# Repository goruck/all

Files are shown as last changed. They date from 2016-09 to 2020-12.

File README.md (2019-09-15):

*NEW - ALL now supports Raspberry Pi 3 running Raspbian Buster + PREEMPT-RT patched kernel 4.19.59-rt23-v7+.*

# What is Alexa Lambda Linux (ALL) Project?
* ALL is an end-to-end HW/SW reference design created to enable quick prototyping and realization of the control and monitoring of things using Amazon’s Alexa.
* ALL includes Amazon’s Alexa Skills Kit and Lambda running in the cloud as well as a local server based on real-time Linux running on the Raspberry Pi.
* ALL also includes machine learning capabilities at the edge. 
* A voice-controlled home security system was built from ALL as an early proof of concept.
* ALL was introduced in late 2015 at https://github.com/goruck/all.

# ALL System Block Diagram

mall blockdia

# ALL Overview
Using voice to interface with devices and services around the home enables a rich and intuitive experience as shown by Amazon's huge successes with FireTV and Echo. However, with the exception of a few 3rd party point solutions such as WeMo, the voice user interface is generally not available in the home. One reason for this is the difficulty and unfamiliarity of the technologies required to enable voice control.

Alexa Lambda Linux (ALL) was developed to help accelerate this learning curve. ALL is a HW/SW reference design meant to enable quick prototyping and realization of the control and monitoring of things using Amazon's Alexa. A voice-controlled home security system was first built from the reference design as proof of concept which was later extended to support machine learning. 

The README below describes the system, the main components, its design, and implementation. It is expected that people will find it useful in creating voice user interfaces of their own using Alexa, Lambda, Linux, and the Raspberry Pi.

Feature | Benefit
------------ | -------------
Integrated with Lambda and ASK | Quick bring-up of new voice controls
Real-time Linux / user space app dev model | Low effort to control fast real-world events
Raspberry PI, open source, AWS services | Low cost and quick deployment
End to end SSL/TLS integration | Customer data security

# Table of Contents
1. [Requirements and System Architecture](https://github.com/goruck/all#requirements-and-system-architecture)
2. [Design and Implementation of the Main Components](https://github.com/goruck/all#design-and-implementation-of-the-components)
   1. [Alexa Intent Schema / Utterance database](https://github.com/goruck/all#alexa-intent-schema--utterance-database)
   2. [AWS Lambda function](https://github.com/goruck/all#aws-lambda-function)
   3. [Raspberry Pi Controller / Server](https://github.com/goruck/all#raspberry-pi-controller--server)
   4. [Keybus to GPIO Interface Unit](https://github.com/goruck/all#keybus-to-gpio-interface-unit)
3. [Machine Learning with ALL](https://github.com/goruck/all/blob/master/README.md#machine-learning-with-all)
   1. [Background Information](https://github.com/goruck/all/blob/master/README.md#background-information)
   2. [Problem Definition](https://github.com/goruck/all/blob/master/README.md#problem-definition)
   3. [Data Preparation](https://github.com/goruck/all/blob/master/README.md#data-preparation)
   4. [Data Analysis](https://github.com/goruck/all/blob/master/README.md#data-analysis)
   5. [Algorithm Evaluation](https://github.com/goruck/all/blob/master/README.md#algorithm-evaluation)
   6. [Implementation](https://github.com/goruck/all/blob/master/README.md#implementation)
   7. [Results](https://github.com/goruck/all/blob/master/README.md#results)
4. [Development and Test environment](https://github.com/goruck/all#development-and-test-environment)
5. [Overall Hardware Design and Considerations](https://github.com/goruck/all#overall-hardware-design-and-considerations)
6. [Bill of Materials and Service Cost Considerations](https://github.com/goruck/all#bill-of-materials-and-service-cost-considerations)
7. [Licensing](https://github.com/goruck/all/blob/master/README.md#licensing)
8. [Contact Information](https://github.com/goruck/all/blob/master/README.md#contact-information)
9. [Appendix](https://github.com/goruck/all#appendix)

# Requirements and System Architecture
Please see below the high-level requirements that the project had to meet.

* Low cost
* Extensible / reusable with low effort
* Secure
* Enable fast prototyping and development
* Include at least one real world application

Meeting these requirements would prove this project useful to a very wide variety of voice interface applications. In addition, implementing a non-trivial "real-world" application would show that the design is robust and capable. Hence the last requirement, which drove the implementation of a voice user interface on a standard home security system, the DSC Power832.

The system needs both cloud and (home-side) device components. Amazon's Alexa was selected as the cloud speech service and Amazon Web Services' Lambda was selected to handle the cloud side processing required to interface between Alexa and the home-side devices. Alexa is a good choice given that its already integrated with Lambda and has a variety of voice endpoints including Echo and FireTV and it costs nothing to develop voice applications via the [Alexa Skills Kit](https://developer.amazon.com/public/solutions/alexa/alexa-skills-kit). [Lambda](https://aws.amazon.com/lambda/) is ideal for quickly handling bursty processing loads, which is exactly what is needed to control things with voice. It also has a free tier under a certain amount of processing and above that its still very inexpensive. So, Alexa and Lambda are reasonable cloud choices given the requirements above.

The [Raspberry Pi 2](https://www.raspberrypi.org/blog/raspberry-pi-2-on-sale/) was designated as the platform to develop the home-side device components( All also supports the Raspberry Pi 3.) The platform has a powerful CPU, plenty RAM, a wide variety of physical interfaces, has support for many OSs, and is inexpensive. It is possible to use an even more inexpensive platform like [Arduino](https://www.arduino.cc/) but given its lower capabilities vis-a-vis the Raspberry PI this would limit the types of home-side applications that could be developed. For example, use of GNU/Linux is desirable in this project for extensibility and rapid development reasons. Arduino isn't really capable of running Linux but the Pi is. The downside of using the Pi plus a high-level OS like vanilla Linux is that the system cannot process quickly changing events (i.e., in "real-time"). On the other hand, the Arduino running bare metal code is a very capable real-time machine. To be as extensible as possible, the system needs to support the development of real-time voice controlled applications and without complex device side architectures like using an Arduino to handle the fast events connected to a Pi to handle the complex events. Such an architecture would be inconsistent with the project requirements. Therefore [real-time Linux](https://wiki.linuxfoundation.org/realtime/start) was chosen as the OS on the Pi. However, this comes with the downsides of using a non-standard kernel and real-time programming is less straightforward than standard application development in Linux userspace.

In the reference design, the Pi's GPIOs are the primary physical interface to the devices around the home that are enabled with a voice UI. This allows maximum interface flexibility, and with using real-time Linux, the GPIO interface runs fast. The reference design enables GPIO reads and writes with less than 60 us latency, vanilla Linux at best can do about 20 ms. Of course, all the other physical interfaces (SPI, I2C, etc.) on the Pi are accessible in the reference design though the normal Linux methods.

The requirements and the analysis above drove a system architecture with the following components.

* Alexa Skills developed using the Alexa Skills Kit
* An AWS Lambda function in Node.js to handle the intent triggers from Alexa and send it back responses from the home device 
* A home device built on Raspberry PI running real-time Linux with a server application developed in C running in userspace
* A hardware interface unit that handled the translation of the electrical signals between the Pi and the security system
* The DSC Power832 security system connected via its Keybus interface to the Pi's GPIOs via the interface unit.

Note that although the development of the architecture described above appears very waterfall-ish, the reality is that it took many iterations of architecture / design / test to arrive at the final system solution.

# Design and Implementation of the Components

## Alexa Skills
Creating Alexa Skills (which are essentially voice apps) is done by using the Alexa Skills Kit. An Amazon applications developer account is required to get access to the [Alexa Skills Kit (ASK)](https://developer.amazon.com/public/solutions/alexa/alexa-skills-kit), one can be created one at https://developer.amazon.com/appsandservices. There's a [getting started guide](https://developer.amazon.com/appsandservices/solutions/alexa/alexa-skills-kit/getting-started-guide) on the ASK site on how to create a new skill. The skill developed to control the alarm panel, named *panel*, used the example skill *color* as a starting point. Amazon makes the creation of a skill relatively easy but careful thinking through the voice interaction is required. The *panel* skill uses a mental model of attaching a voice command to every button on the alarm's keypad and an extra command to give the status of the system. The alarm system status is the state of the lights on the keypad (e.g., armed, bypass, etc). Four-digit code input is also supported, which is useful for a PIN. The Amazon skill development tool takes you through the following steps in creating the skill:

1. Skill Information - Invocation Name, Version, and Service Endpoint (the Lambda ARN in this project)
2. Interaction Model - Intent Schema, Custom Slot Types, and Sample Utterances
3. Test
4. Description
5. Publishing Information (the *panel* skill is not currently published)

The creation of the *panel* skill required inputting of an [Intent Schema](https://github.com/goruck/all/blob/master/ask/IntentSchema.txt) (which defines the voice interaction model), [sample utterances](https://github.com/goruck/all/blob/master/ask/SampleUtterances.txt), and [custom slot definitions](https://github.com/goruck/all/blob/master/ask/CustomSlotTypes.txt) which are essentially elaborations of the values of parameters used in the Intent Schema. The ASK service will generate a voice model from these inputs. 

The table below shows some of the mapping between example user requests and the sample utterance syntax used in the interaction model. 

Example User Request | Sample Utterance
---------------------|------------------
“Alexa, ask Panel for its status” | WhatsMyStatusIntent its status
“Alexa, ask Panel about its status” |WhatsMyStatusIntent its status
“Alexa, ask Panel for the status” | WhatsMyStatusIntent the status
“Alexa, ask Panel about the status” | WhatsMyStatusIntent the status
“Alexa, ask Panel for status” | WhatsMyStatusIntent status
“Alexa, ask Panel about status” | WhatsMyStatusIntent status
“Alexa, ask Panel for the status” | WhatsMyStatusIntent the status
“Alexa, ask Panel about the status” | WhatsMyStatusIntent the status
“Alexa, ask Panel what is the status” | WhatsMyStatusIntent what is the status
“Alexa, ask Panel what the status is” | WhatsMyStatusIntent what the status is
“Alexa, ask Panel what's the status” | WhatsMyStatusIntent what's the status
“Alexa, ask Panel to give me the status” | WhatsMyStatusIntent give me the status
“Alexa, ask Panel to give me its status” | WhatsMyStatusIntent give me its status
“Alexa, ask Panel to tell me the status” | WhatsMyStatusIntent tell me the status
“Alexa, ask Panel to tell me its status” | WhatsMyStatusIntent tell me its status
"Alexa, ask Panel for key pound" | MyNumIsIntent key {Keys}
"Alexa, ask Panel for button star" | MyNumIsIntent button {Keys}
"Alexa, ask Panel for key pad button 0" | MyNumIsIntent key pad button {Keys}
"Alexa, ask Panel for 8" | MyNumIsIntent {Keys}
"Alexa, ask Panel for pin 1234" | MyCodeIsIntent pin {Code}
"Alexa, ask Panel for code 5678" | MyCodeIsIntent code {Code}
"Alexa, ask Panel for 4545" | MyCodeIsIntent {Code}

The "LIST_OF_KEYS" slot enables the intent "MyNumIsIntent" to activate when Alexa hears the name of the buttons on the keypad defined by the slot. The intent "WhatsMyStatusIntent" activates when Alexa hears any of the status related utterances listed above. The intent "MyCodeIsIntent" activates when Alexa hears a 4-digit code. When the intents activate, they cause the service endpoint Lambda function to run and perform specific processing depending on the user intent.

The skill is invoked by saying to Alexa "ask panel" or "tell panel".

## AWS Lambda function
An Amazon Web Services account is needed to use Lambda, one can be created at at https://aws.amazon.com/. Like all AWS products, there is good [documentation](https://aws.amazon.com/lambda/) available on the AWS site that should be read to come up to speed, if not already familiar. Still it can be challenging to use the product, if unfamiliar with javascript, Node, and asynchronous programming which are all essential to using Lambda. Several books and articles including [*Sams Teach Yourself Node.js in 24 Hours*](http://smile.amazon.com/dp/0672335956) by Ornbo, [*JavaScript: The Good Parts*](http://smile.amazon.com/dp/0596517742) by Crockford, and [*Asynchronous programming and continuation-passing style in JavaScript*](http://www.2ality.com/2012/06/continuation-passing-style.html) by Rauschmayer can help to accelerate the learning curve. Lambda and Node.js is very well-suited to scale cloud side processing associated with applications like voice control, given that Lambda was designed to handle bursty applications and the non-blocking I/O benefits of Node.js.

The *color* skill and Lambda function example provided by ASK was used as a template to create the Lambda function for *panel*. Since the Lambda function needed to talk to a remote Raspberry Pi server, that functionality was added as well as modifying the logic and speech responses to suit the alarm application. The Lambda code uses the Node.js tls method to open, read, and write a TCP socket that connects to the remote Pi server which sends commands to and reads status from the panel. The tls method provides both authentication and encryption between the Lambda client and the Pi server. One of the biggest challenges in this development is the placement of the  callbacks that returned responses back to Alexa due to the async nature of Node.js. The rest of the Lambda function development was straightforward. 

The Lambda code is divided up into three parts, [all.js](https://github.com/goruck/all/blob/master/lambda/all.js) contains most of the functions required to process the speech intents from the Alexa service and interface to the local Pi in a client - server model. However, some Lambda code requires it to be released under the Amazon License which is in the [amzn](https://github.com/goruck/all/tree/master/lambda/amzn) directory. Lastly, the Lambda code common to all.js and the code in the amzn directory is in [shared.js](https://github.com/goruck/all/blob/master/lambda/shared.js).

## Raspberry Pi Controller / Server

### Real-time Linux
The Linux disto on the Pi is based on Debian 10 "Buster" with a custom built [Raspberry Pi Linux 4.19.y kernel](https://github.com/raspberrypi/linux/tree/rpi-4.19.y-rt) patched with rt-patch and configured as a fully preemptible kernel. The kernel was cross-compiled on a Linux host using the official [Raspberry Pi instructions](https://www.raspberrypi.org/documentation/linux/kernel/building.md) and [LeMaRiva's excellent HOWTO](https://lemariva.com/blog/2019/09/raspberry-pi-4b-preempt-rt-kernel-419y-performance-test) as guides. Also the wiki [real-time Linux](https://wiki.linuxfoundation.org/realtime/start) is an invaluable source of information on the rt-patch and how to write real-time code.

The latency of the patched kernel was measured using [Cyclictest](https://wiki.linuxfoundation.org/realtime/documentation/howto/tools/cyclictest/start) which showed a worse case latency of less than 135 us. So, that seemed to indicate that applications could reliably respond to events up to about 7.4 kHz which is sufficient for this application which needs to respond to events at a 1 KHz rate (see below).

The distribution of the latency on the patched kernel as measure by Cyclictest is shown below.

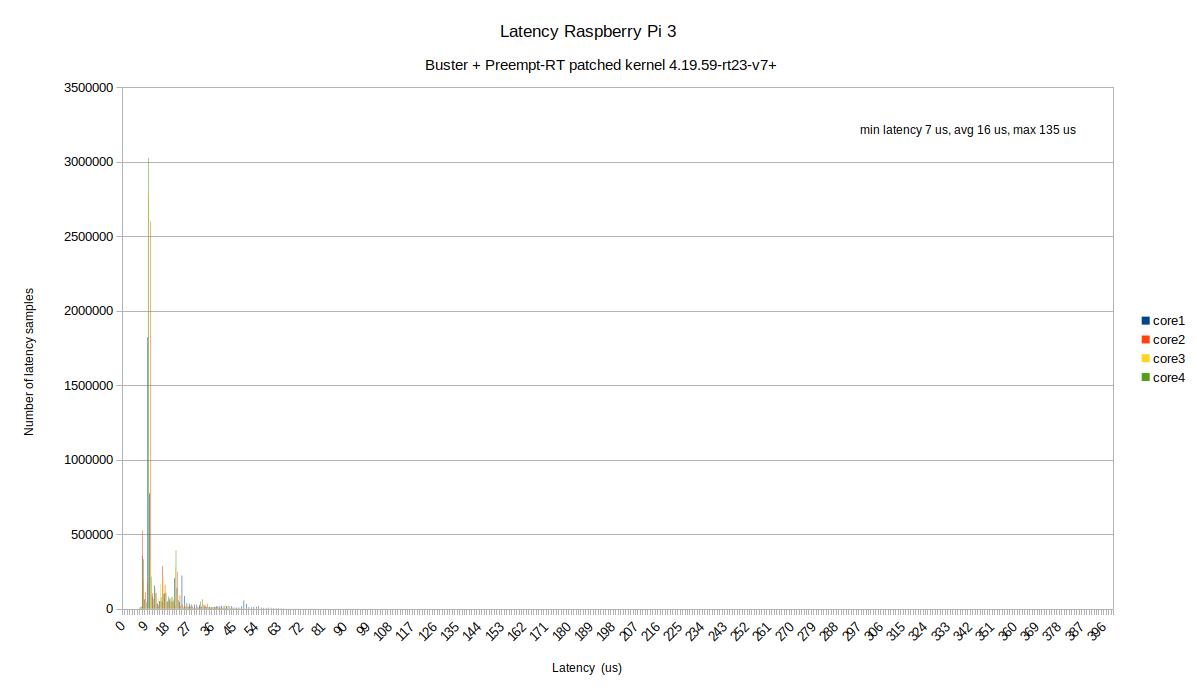
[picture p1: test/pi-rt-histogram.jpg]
pi latency


### Controller / Server Application
The application code on the Pi emulates a DSC keypad controller running in the Linux system's userspace. The application code in its entirety can be found [here](https://github.com/goruck/all/blob/master/rpi/kprw-server.c), this section captures important design considerations that are not obvious from the code itself or the comments therein.

The DSC system is closed and proprietary and besides the installation and programming information in the DSC manuals and what hackers have managed to figured out and posted on the Internet and GitHub, there isn't much information available about the protocol it uses to communicate with its keypads. Also, much of of what is on the Internet relies on using an IP interface bridge like this [one](http://www.eyezon.com/?page_id=176) from Eyezon. A bridge like this instead of the code on the Raspberry Pi could have been used in this project but that would have made the reference design much less generic (and much less fun to develop). A lot of useful information on how to hack the DSC system can be found in the [Arduino-Keybus](https://github.com/emcniece/Arduino-Keybus) GitHub repo, but this project uses an Arduino which was ruled out (see above) and it was read-only. Still, it is very educational. Although these sources helped, a lot of reverse engineering was required to figure out the protocol used on the DSC Keybus. The reverse engineering mainly consisted of using an early version of the application code to examine the bits sent from the panel to the keypads and the keypads to the panel in response to keypad button presses and other events, like motion and door / window openings and closings. It was determined that the first two bytes of each message indicates its type, followed by a variable number of data bits including error protection. For example a message with its first two bytes equal to 0x05 is telling the keypad to illuminate specific status LEDs, such as BYPASS, READY, etc and a message type equal to 0xFF indicates keypad to panel data is being sent. See the *decode()* function in the application code for details regarding the various message types and their contents.

The application code consists of three main parts:

* A thread called *panel_io()* that handles the bit-level processing needed to assemble messages from the keybus serial data
* A thread called *msg_io()* that handles the message-level output processing
* A server called *panserv()* running in the main thread that communicates with an external client for commands and status

The application code directly accesses the GPIO's registers for the fastest possible reads and writes. The direct access code is based on [this](http://elinux.org/RPi_GPIO_Code_Samples#Direct_register_access) information from the Embedded Linux Wiki at elinux.org. The function *setup_io()* in the application code sets up a memory regions to access the GPIOs. The information in the Broadcom BCM2835/6 ARM Peripherals document is very useful to understand how to safely access the Pi's processor peripherals. It is [here](http://elinux.org/RPi_Documentation) on the Embedded Linux Wiki site.

Inter-thread communication is handled safely via read and write FIFOs without any synchronization (e.g., using a mutext). Its not desirable to use conventional thread synchronization methods since they would block the *panel_io()* thread. There is no way (to my knowledge) to tell the panel not to send data on the keybus, so if *panel_io()* was blocked by another thread accessing a shared FIFO, the application code would drop messages. A good solution to this problem was found in the article [Creating a Thread Safe Producer Consumer Queue in C++ Without Using Locks](http://blogs.msmvps.com/vandooren/2007/01/05/creating-a-thread-safe-producer-consumer-queue-in-c-without-using-locks/) by Vandooren, which is what was implemented with a few modifications.

Running code under real-time Linux requires a few special considerations. Again, the [real-time Linux](https://rt.wiki.kernel.org/index.php/Main_Page) wiki was used extensively to guide the efforts in this regard. The excellent book [The Linux Programming Interface](http://man7.org/tlpi/) by Kerrisk also was very helpful to understand more deeply how the Linux kernel schedules tasks. There are three things needed to be set by a task in order to provide deterministic real time behavior:

1. Setting a real time scheduling policy and priority by use of the *sched_setscheduler()* system call and its pthread cousins. Note that *panel_io()*, *message_io()*, and *main()* were all given the same scheduling policy (SCHED_FIFO) but *panel_io()* has a higher priority than *message_io()* and *main()*. This was done to ensure that the bit-level processing would have enough time to complete. 
2. Locking memory so that page faults caused by virtual memory will not undermine deterministic behavior. This is done with the *mlockall()* system call. 
3. Pre-faulting the stack, so that a future stack fault will not undermine deterministic behavior. This is done by simply accessing each element of the program's stack by use of the *memset()* system call. 

Extensive use of the *clock_nanosleep()* function from librt is used in the code. For example, its use is shown in the *panel_io()* thread where it awakens the thread every INTERVAL (10 us) to read and write to the GPIOs driving the keybus clock and data lines (via the interface unit). The thread contains logic to detect the start of word marker, to detect high and low clock periods, and to control precisely when the GPIOs are read and written. The below taken from *panel_io()* causes the thread to wait for valid data before reading the GPIO.

```c
t.tv_nsec += KSAMPLE_OFFSET;
tnorm(&t);
clock_nanosleep(CLOCK_MONOTONIC, TIMER_ABSTIME, &t, NULL); // wait KSAMPLE_OFFSET for valid data
wordkr_temp = (GET_GPIO(PI_DATA_IN) == PI_DATA_HI) ? '0' : '1'; // invert
```

Even though the *panel_io()* is given higher priority than the other two threads, other critical threads in the Linux kernel must have higher still priority for the overall system to function. Therefore it is possible that a higher priority kernel task could preempt *panel_io()* and cause it to drop bits. The real-time Linux wiki suggests this solution:

*"In general, I/O is dangerous to keep in an RT code path. This is due to the nature of most filesystems and the fact that I/O devices will have to abide to the laws of physics (mechanical movement, voltage adjustments, <whatever an I/O device does to retrieve the magic bits from cold storage>). For this reason, if you have to access I/O in an RT-application, make sure to wrap it securely in a dedicated thread running on a disjoint CPU from the RT-application."* 

Based on this, the *panel_io()* thread was locked to its own CPU and the other threads are locked to the other three CPUs (its really great to have four CPUs at one's disposal). The application code sets the thread CPU affinity as shown below. 

```c
// CPU(s) for main, predict and message i/o threads
  CPU_ZERO(&cpuset_mio);
  CPU_SET(1, &cpuset_mio);
  CPU_SET(2, &cpuset_mio);
  CPU_SET(3, &cpuset_mio);
  CPU_ZERO(&cpuset_main);
  CPU_SET(1, &cpuset_main);
  CPU_SET(2, &cpuset_main);
  CPU_SET(3, &cpuset_main);
  // CPU(s) for panel i/o thread
  CPU_ZERO(&cpuset_pio);
  CPU_SET(0, &cpuset_pio);
```

With the threads pinning to the CPUs in this way and with the priority of *panel_io()* being greater than the other two threads in the application code (but not greater than the kernel's critical threads), the system exhibits robust real-time performance.

The server uses openSSL for authentication and encryption. For development and test purposes self-signed certificates are used. The cert and key pairs are generated with the following commands.

```bash
# Step 1. Generate ca private key
$ openssl genrsa -out /home/pi/certs/ca/ca.key 4096
# Step 2. Create self-signed ca cert, COMMON_NAME="My CA"
$ openssl req -new -x509 -days 365 -key /home/pi/certs/ca/ca.key -out /home/pi/certs/ca/ca.crt -sha256
# 
# Step 3. Create client private key
$ openssl genrsa -out /home/pi/certs/client/client.key 2048
# Step 4. Create client cert signing request, COMMON_NAME="Client 1"
$ openssl req -new -key /home/pi/certs/client/client.key -out /home/pi/certs/client/client.csr -sha256
# Step 5. Create signed client cert
$ openssl x509 -req -days 365 -in /home/pi/certs/client/client.csr -CA /home/pi/certs/ca/ca.crt -CAkey /home/pi/certs/ca/ca.key -set_serial 01 \
-out /home/pi/certs/client/client.crt -sha256
# 
# Step 6. Create server private key
$ openssl genrsa -out /home/pi/certs/server/server.key 2048
# Step 7. Create server cert signing request, COMMON_NAME="localhost"
$ openssl req -new -key /home/pi/certs/server/server.key -out /home/pi/certs/server/server.csr -sha256
# Step 8. Create signed server cert, where "key.ext" contains "subjectAltName = IP:xxx.xxx.xxx.xxx"
$ openssl x509 -req -days 365 -in /home/pi/certs/server/server.csr -CA /home/pi/certs/ca/ca.crt -CAkey /home/pi/certs/ca/ca.key -set_serial 02 \
-out /home/pi/certs/server/server.crt -sha256 -extfile /home/pi/certs/server/key.ext
# 
# Step 9. Copy client key pair and CA certificate to Lambda
$ cp /home/pi/certs/client/client.crt /home/pi/all/lambda
$ cp /home/pi/certs/client/client.key /home/pi/all/lambda
$ cp /home/pi/certs/ca/ca.crt /home/pi/all/lambda
```

Note: replace the X's in key.ext with the IP address or hostname of your server.

Production code should use certificates signed by a real CA. The server also uses TCP Wrapper daemon for secure access. TCP Wrapper uses the *hosts_ctl()* system call from libwrap library to limit client access via the rules defined in /etc/host.deny and /etc/host.allow files. The rules are set so that only clients with local IP addresses and AWS IP addresses are allowed access to the server.

The application code needs to be compiled with the relevant libraries and executed with su privileges, per the following.

```bash
# Install libs if needed.
$ sudo apt install libwrap0-dev libssl-dev
# Compile kprw-server.c.
# To enable R logging, add -DRLOG=\"/home/pi/all/R/rlog.txt\" (change path as required).
# To output status messages to stdout, add -DVERBOSE.
# To run a real-time safe test at start of program, add -DTESTRT.
$ gcc -Wall -o kprw-server kprw-server.c -lrt -lpthread -lwrap -lssl -lcrypto
# Start program.
# PORTNUM=69840 # TCP port number for the server to use (change as required).
$ sudo ./kprw-server $PORTNUM
```

### Startup
The Raspberry Pi is used here as an embedded system so it needs to come up automatically after power on, including after a possible loss of power. The application code defines the GPIOs as follows:

```c
// GPIO pin mapping.
#define PI_CLOCK_IN	(13) // BRCM GPIO13 / PI J8 Pin 33
#define PI_DATA_IN	(5)  // BRCM GPIO05 / PI J8 Pin 29
#define PI_DATA_OUT	(16) // BRCM GPIO16 / PI J8 Pin 36
``` 

These GPIOs need to be in a safe state after power on and boot up. Per the Broadcom BCM2835/6 ARM Peripherals document, these GPIOs are configured as inputs at reset and the kernel doesn't change that during boot, so they won't cause any the keybus serial data line to be pulled down before the application code initializes them. The BRCM GPIO16 was selected for the active high signal that drives the keybus data line since that GPIO has the option of being driven low from an external pull down. Other GPIOs have optional pull-ups. Even though the pull resistors are disabled by default, this removes the possibility of the keybus data line becoming active if software somehow enabled the pull resistor by mistake.

A known problem of the Raspbian Preempt-RT patches is that the IRQ/39-dwc_otg process can use a lot the CPU (~30%) which is caused by servicing the USB irq. Although this should not affect the real-time performance of this application given the thread priority settings, the USB ports can be disabled if they are not being. Since the RPi3's wifi chip is connected via SDIO to the processor and nothing else was needed to be connected to the USB ports they are disabled on startup in this configuration to improve the responsiveness of the system. This is done by [power-off-usb.sh](./scripts/power-off-usb.sh) script which is run by /etc/rc.local at startup. 

The kprw-server application is run as a Linux service enabled to run at boot time. See [kprw-server.service](./rpi/kprw-server.service).

## Keybus to GPIO Interface Unit

### Keybus Electrical and Timing Characteristics
The keybus is a DSC proprietary serial bus that runs from the panel to the sensors and controller keypads in the house. This bus needs to understood from an electrical, timing, and protocol point of view (see above) before the Pi can be interfaced to the panel. There isn't a lot of information on the keybus other than what's in the DSC installation manual and miscellaneous info on the Internet posted by hackers. Essentially, this is a two wire bus with clock and data, plus ground and the supply from the panel. The supply is 12 V (nominal) and the clock and data transition between zero volts and the supply voltage level (i.e., 0 to 12 V nominally but could be a bit more or less (~ +/-10%) depending on the specific panel). The large voltage swings make sense given that it provides good noise immunity against interference picked up from long runs of the bus through the house. The DSC manual states that the bus supply can source a max of 550 mA. The sum of the current from all the devices presently on the bus was about 400 mA. This meant that the interface unit could draw no more than 150 mA.

An oscilloscope was used to reverse engineer the protocol. Some screen-shots and analysis from them are below.

whole-word-ann

This shows an entire word with the start of new word marker, which is the clock being held high for a relatively long time. The clock rate when active is 1 KHz. The messages between the panel and keypads are of variable length. The typical message from the panel to the keypads is 43 bits (43 ms in duration) and the start of the new word clock marker is about 15 ms. Thus, a typical message time including start of new marker is about 58 ms. Messages can be up to 62 bits long but they are not frequent. 

data-clock-close

This shows a closer view of the clock and data, with data being sent between the panel and keypad and vice-versa. Data from the panel to the keypads transitions on the rising edge of the clock and becomes valid about 120 us later. Data from the keypads to the panel transitions at falling edge of the clock is likely registered in the panel on the next rising edge of the clock. The keypad data needs to be held for at least 25 us after the rising edge of the clock for it to be properly registered. Timers in the Pi's application code must adhere to these values for reliable data transfers to happen. The spikes at 2.5 and 4.5 ms are most likely due to the pull-up resistor on the data line in the panel causing it to be pulled high before the driver on the keypad has a chance to pull it low, which happens when the keypad sends a 0 bit to the panel.

From this data, it is clear that the panel's data line is bidirectional (with direction switched by clock level) and pulled up internally when configured as an input. The strength of the pull-up resister needs to be known in order to design the interface circuit correctly and via experimentation it was determined to be approximately 5 KΩ.

Note that a means to prevent or mitigate keybus data corruption needs to be implemented since ALL may try to write to the panel at the same time as a keypad. This is done in the rpi code by checking for very short words sent by the panel on the keybus. The panel outputs short words (usually 9-bits) which are ignored as invalid since these short words are usually associated with the simultaneous transfer of keypad data to the panel (recall from above the keybus is bidirectional and bits are transferred on the rising and falling edge of the clock). This keypad data is sent in response to a panel keypad query command that was sent previously. These commands include those messages starting with 0x051, 0x0593, 0x11 and possibly others.

### Raspberry Pi GPIO Electrical Characteristics
Data on the electrical characteristics of the Pi's GPIOs is also required to design the interface. There is not really the right level of detail available from the Raspberry Pi standard information. But there is excellent information on the Mosaic Industries' website [here](http://www.mosaic-industries.com/embedded-systems/microcontroller-projects/raspberry-pi/gpio-pin-electrical-specifications). This information is super helpful and detailed. Some of the key points from the article are below. 

* These are 3.3 volt logic pins. A voltage near 3.3 V is interpreted as a logic one while a voltage near zero volts is a logic zero. A GPIO pin should never be connected to a voltage source greater than 3.3V or less than 0V, as prompt damage to the chip may occur as the input pin substrate diodes  conduct. There may be times when you may need to connect them to out ­of ­range voltages – in those cases the input pin current must be limited by an external resistor to a value that prevents harm to the chip. I recommend that you never source or sink more than 0.5 mA into an input pin
* To prevent excessive power dissipation in the chip, you should not source/sink more current from the pin than its programmed limit. So, if you have set the current capability to 2 mA, do not draw more than 2 mA from the pin
* Never demand that any output pin source or sink more than 16 mA
* Current sourced by the outputs is drawn from the 3.3 V supply, which can supply only 50 mA maximum. Consequently, the maximum you can source from all the GPIO outputs simultaneously is less than 50 mA. You may be able to draw transient currents beyond that limit as they are drawn from the bypass capacitors on the 3.3 V rail, but don't push the envelope! There isn't a similar limitation on sink current. You can sink up to 16 mA each into any number of GPIO pins simultaneously. However, transient sink currents do make demands on the board's bypass capacitors, so you may get into trouble if all outputs switch their maximum current synchronously
* Do not drive capacitive loads. Do not place a capacitive load directly across the pin. Limit current into any capacitive load to a maximum transient current of 16 mA. For example, if you use a low pass filter on an output pin, you must provide a series resistance of at least 3.3V/16mA = 200 Ω

### Interface Circuit Design
Its desirable to electrically isolate the panel and Pi to prevent ground loops and optoisolators are an obvious choice. But they do consume a fair amount of current and the keybus data and clock lines cannot supply enough to directly drive them. Therefore, the keybus clock and data lines have buffers (CD4050) between them and the optoisolators. Out of an abundance of caution, buffers (74HC126) were also added between the clock and data optoisolators and the Pi's GPIOs, but they are not really needed since the Pi's GPIOs come out of reset being able to supply or sink 8 mA while the interface circuit only needs a 2 mA supply. The '126 buffers were removed in the final design. A high Current Transfer Ratio (CTR) optoisolator configured to drive a FET with logic-level gate voltage threshold was used to pull down the data line with sufficient strength. The other optoisolators are high CTR as well to minimize current draw from the panel. The interface schematic is shown below.

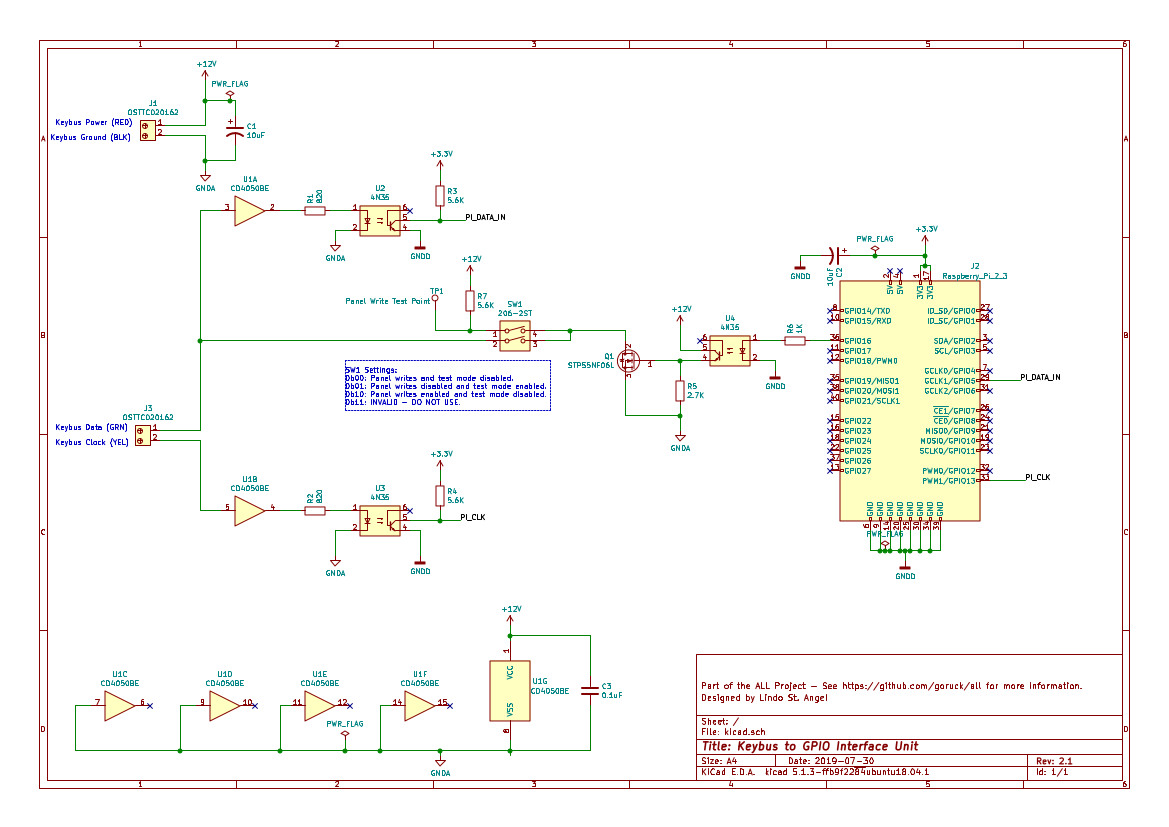
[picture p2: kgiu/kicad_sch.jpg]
interface


# Machine Learning with ALL
Adding machine learning (ML) capabilities to ALL was mainly motivated by a desire to use Alexa to help train a ML algorithm in an intuitive and low-friction manner by employing voice to ground truth (or 'tag') observations. Also since ALL uses a home security system as a proof-of-concept, ML seemed to be a natural fit given the amount of data captured by the security system's sensors. Door, window, and motion data is continually captured which reflects the movement of people into and around the house. Of course, normally this data is used for security monitoring purposes but here the goal of adding machine learning to ALL was to use this data to reliably predict patterns of people movement around the house that would trigger appropriate actions automatically. Using ML as described below can also be used to become familiar with the topic itself since the application is fairly straightforward and tractable.

Its important to note that simple rule based algorithms can be employed instead of ML to trigger actions based on the sensor data. However, this is really only feasible for the most basic patterns of movement around the house. 

## Background Information
### Training ML Models *(This section adapted from [here](http://docs.aws.amazon.com/machine-learning/latest/dg/training-ml-models.html))*
The process of training an ML model involves providing an ML algorithm (that is, the learning algorithm) with training data to learn from. The term ML model refers to the model artifact that is created by the training process.

The training data must contain the correct answer, which is known as a response. The learning algorithm finds patterns in the training data that map the input data predictors to the response (the answer that you want to predict), and it outputs an ML model that captures these patterns.

The ML model is used to get predictions on new data for which a response is not known.

### Steps to build and train a predictive ML model
1. Define the problem that predictive ML model will solve for.
2. Prepare the data that will be used to train the ML model.
3. Analyze the training data to help guide ML algo selection. 
4. Select a suitable algorithm for the ML model. 
5. Evaluate and optimize the ML model’s predictive accuracy.
6. Use the ML model to generate predictions.

### R
The popular open-source software R was selected as the main ML tool and was intended to be used for both modeling and embedded real-time purposes which helps to accelerate development by reusing code. The excellent book [An Introduction to Statistical Learning](http://smile.amazon.com/dp/B01IBM7790) was extensively used as both a learning guide to ML and to R.

The R software package was downloaded from [The R Project for Statistical Computing](https://www.r-project.org/) website and compiled on the Raspberry Pi since there are no recent pre-compiled packages available for Raspbian Wheezy. The following steps are required to install R on the Pi.

```bash
$ cd ~
$ wget http://cran.rstudio.com/src/base/R-3/R-3.6.1.tar.gz
$ mkdir R_HOME
$ mv R-3.6.1.tar.gz R_HOME/
$ cd R_HOME/
$ tar zxvf R-3.6.1.tar.gz
$ cd R-3.6.1/
$ sudo apt-get install gfortran libreadline-dev libx11-dev libxt-dev \
libbz2-dev liblzma-dev libpcre3-dev libcurl4-gnutls-dev
$ ./configure
$ make
$ sudo make install
```

Note that this installs R version 3.6.1 which is the latest compatible version for Raspbian Buster.

## Problem Definition
It is important to first understand and clearly describe the problem that is being solved including how training will be done. Here, the problem is to accurately predict a person's movement into and through the house using the security system's motion and door sensors (the window sensors are ignored for the present) and to take action on that prediction.

The proof of concept system is installed in a two story house with a detached playroom / garage in the rear, accessible via a short walk through the backyard. The relevant sensors are as follows.

Zone | Sensor
-----|-------
1  | Front Door
16 | Family Room Slider (rear house exit)
27 | Front Motion
28 | Hall Motion (first floor)
29 | Upstairs Motion (second floor hall)
30 | Playroom Motion (in detached unit behind house)
32 | Playroom Door

Thus, as a person traversed through the zones listed above the problem is to predict the path taken, speed of travel and direction of travel. An example path could be a person arriving home, entering through the front door, walking into the family room via the first floor hall, exiting the house through the rear family room slider door and into the playroom. Patterns can also be time of day dependent (example being a person arriving home around the same time in the evening and following the above path). These sensors and the time of day will be used to fit the model and as inputs to the model to make predictions. 

A related problem is how to train the model in the most intuitive and easiest manner possible for the user. A good solution is tagging the patterns as the occur with voice via Alexa. For example, if a person walked the above pattern at 7:00 PM, she would tell Alexa that ("Alexa, I'm home") which would trigger a sequence of events to capture an observation and update the ML model.

A typical use case is shown in the figure below, where a person arrives home at a specific time and turns on the TV. The person would tell Alexa this happened and after a fashion the TV would automatically be turned on (and perhaps Fire TV would stream a favorite show) when this pattern is detected.

typ-usecase

## Data Preparation
Considerable thought was put into understanding the sensor information required to develop the ML model. The native output from the sensors is binary - the sensor is either activated by movement or its not due to lack of movement. For security monitoring purposes this is normally sufficient but this binary information needs to be transformed into a continuous time series to be useful as inputs to the model described above. This transformation is accomplished by applying a time-stamp to every activation or deactivation of a sensor, which is called the 'absolute' time of an observation. The timestamped sensor data is not used directly to build / update the ML model or predict a pattern. Instead a version of the timestamped data is used which is the last activation / deactivation time of a sensor relative to the current observation time. The relative data is required to ensure that the training data used to build the model are consistent with new data used for prediction. An example transformation for a four sensor zone example is shown in the figure below.

transform

Relative activation and deactivation times for each sensor along with the time and date, sample time, and the response ground truth for a specific pattern form a training predictor vector based on a single observation. A collection of these vectors form a dataset from which a model can be generated. Similarly, a test vector is formed from new sensor data (without the ground truth) that is used by the model to make predictions. 

An example training predictor vector is shown below, where 'clock' is the time and date of the observation, 'sample' is a time-stamp value in seconds (derived from Linux system time of the server), 'zaNN' is the sensor activation time in seconds relative to the time-stamp, 'zdNN' is the sensor deactivation time in seconds relative to the time-stamp, and 'patternNN' is the response ground truth for a specific pattern for the given observation.

| clock | sample  | za1 | za2 | za3 | za4 | za5 | za6 | za7 | za8 | za9 | za10 | za11 | za12 | za13 | za14 | za15 | za16 | za17 | za18 | za19 | za20 | za21 | za22 | za23 | za24 | za25  | za26  | za27 | za28 | za29 | za30 | za31 | za32 | zd1 | zd2 | zd3 | zd4 | zd5 | zd6 | zd7 | zd8 | zd9 | zd10 | zd11 | zd12 | zd13 | zd14 | zd15 | zd16 | zd17 | zd18 | zd19 | zd20 | zd21 | zd22 | zd23 | zd24 | zd25 | zd26 | zd27 | zd28 | zd29 | zd30 | zd31 | zd32 | pattern1 | pattern2 | pattern3 | pattern4 | pattern5 | pattern6 | pattern7 | pattern8 | pattern9 | pattern10 |
|---|---|---|---|---|---|---|---|---|---|---|---|---|---|---|---|---|---|---|---|---|---|---|---|---|---|---|---|---|---|---|---|---|---|---|---|---|---|---|---|---|---|---|---|---|---|---|---|---|---|---|---|---|---|---|---|---|---|---|---|---|---|---|---|---|---|---|---|---|---|---|---|---|---|---|---|
| 2016-07-30T21:54:37.950Z | 4134765 | -14172 | -4134765 | -4134765 | -4134765 | -4134765 | -4134765 | -4134765 | -4134765 | -4134765 | -4134765 | -4134765 | -4134765 | -4134765 | -4134765 | -4134765 | -51  | -4134765 | -4134765 | -4134765 | -4134765 | -4134765 | -4134765 | -4134765 | -4134765 | -8066 | -6541 | -31  | -37  | -12  | -70  | -4134765 | -72  | -14164 | -4134765 | -4134765 | -4134765 | -4134765 | -4134765 | -4134765 | -4134765 | -4134765 | -4134765 | -4134765 | -4134765 | -4134765 | -4134765 | -4134765 | -47  | -4134765 | -4134765 | -4134765 | -4134765 | -4134765 | -4134765 | -4134765 | -4134765 | -4134765 | -4134765 | -30  | -32  | -6 | -68  | -4134765 | -69  | NA | NA | NA | NA | NA | NA | NA | TRUE | NA | NA |

## Data Analysis
Once it was understood how to form a relevant sensor dataset for the model the next step was to discover and expose the structure in the dataset. Using the above transformations, a dataset of about 300 observations was collected and visualized in scatterplots using R's graphical capabilities. The R code that generated these plots can be found [here](https://github.com/goruck/all/blob/master/R/genScatterPlots.R) and the observation dataset can be found [here](https://github.com/goruck/all/blob/master/R/panelSimpledb.csv).

Eight unique patterns were used to generate the observations. Each pattern corresponds to a path, direction, and speed of a person walking though the house and the approximate hour of the day this pattern occurred. The training was done by walking the pattern a few times and then invoking an Alexa skill that aquired the sensor data. The patterns and the zones they activate are summarized in the table below.

Pattern Number | Path | z1 | z16 | z27 | z28 | z29 | z30 | z32 | clock
-------|---------|----|-----|-----|-----|-----|-----|-----|-------
0 | virtual pattern that indicates no path has been classified | N | N | N | N | N | N | N | N
1 | from front door into playroom in the evening | Y | Y | Y | Y | N | Y | Y | ~7:00PM
2 | from outside into playroom | N | N | N | N | N | Y | Y | N
3 | from family room into playroom | N | Y | N | N | N | Y | Y | N
4 | slow walk from kid's rooms to playroom | N | Y | Y | Y | Y | Y | Y | N
5 | fast walk from kid's rooms to playroom | N | Y | Y | Y | Y | Y | Y | N
6 | from master bedroom to kitchen in the early morning via living room | N | N | Y | N | Y | N | N | ~4:00AM
7 | reserved | N | N | N | N | N | N | N | N
8 | from playroom to kid's rooms | N | Y | Y | Y | Y | Y | Y | N
9 | reserved | N | N | N | N | N | N | N | N
10 | reserved | N | N | N | N | N | N | N | N

An example R generated scatterplot for the response 'pattern6' (walking from the upstairs to the kitchen via the front hall in the early morning) is shown in the figure below. Note that a temporal filter is always applied to the data that limits sensor times to 120 seconds which is about the maximum time it takes a person to walk a particular path through the house. Sensor data outside this window is not relevant. 

pattern6scatterplot

Another example scatterplot for 'pattern4' (slow walk from the kid's rooms to the playroom via the front hallway) is shown in the figure below.

pattern4scatterplot

The axis for each plot is time in seconds from 0 to -120 with the exception of clock which is in hours from 0 to 23. The red dots are samples where the response is true, the black dots are where the response is false. From the scatterplots, the following can be determined.

* The data is not linearly separable between the true and false responses, so a non-linear model will be required.
* The true responses tend to be tightly clustered and surrounded by false responses, perhaps indicating a higher order non-linear model will be needed.
* The sensor predictors tend to be related by the fact they are offset in time from each other. The offset forms the basic pattern that needs to be classified.
* The data appears relatively unstructured in that there are not well defined regions of true and false responses (the 'decision boundary'). 
* Some patterns will have predictors that are not relevant since in general a path does not involve every sensor.
* An ensemble of two models may be required, one with clock as a predictor and one without it to handle observations taken around a particular time and those at random times.
* The data will need to be normalized given that the clock and sensor activation times are in different units. 

## Algorithm Evaluation
Now that the structure in the dataset is understood candidate model algorithms were evaluated using an R-based test harness.

Given the relatively unstructured decision boundary and non-linear nature of the dataset, the K-Nearest Neighbors (KNN), Random Forests and Support Vector Machine (SVM) algorithms are reasonable choices given that they are well-understood, non-parametric methods and have high flexibility (note that non-parametric models generally have the disadvantage of growing more complex as the number of observations increases). See [An Introduction to Statistical Learning](http://smile.amazon.com/dp/B01IBM7790) for details about the KNN, Random Forests, and SVM algorithms and their relative strengths and weaknesses. In the interest of time, only KNN and SVM approaches were evaluated and overall SVM seemed to offer better over performance (at the expense of more complexity) for the sensor dataset and so therefore was selected. The dataset provides a set of training observations that can be used to build a SVM-based multiple-class classifier. SVM uses the one-versus-one for multiple classification. More information about using SVMs in R can be found [here](https://cran.r-project.org/web/packages/e1071/vignettes/svmdoc.pdf).

An SVM with a radial kernel was selected given the non-linear class boundaries of the datasets. Cross-validation was used to select the best values of the parameters *gamma* and *cost* associated with the model. The R script to generate and test the SVM model can be found [here](https://github.com/goruck/all/blob/master/R/genSvmTest.R) with the dataset [here](https://github.com/goruck/all/blob/master/R/panelSimpledb.csv). The script generates confusion matrices for training and validation data.

The confusion matrix for the training data shown below. The numbers in the row and column headers represent the pattern number classified with 0 being the null case (i.e., no pattern was classified). Note that only patterns 1 through 8 were used and with clock as a factor in these examples. This data indicates that model is trained very well except for pattern 8. This is most likely because pattern does not yet have enough training samples in the current dataset. 

```text
> ### training error of optimal svm model with clock as a predictor
> svmPred = predict(svmOpt, trainData, probability = TRUE)
> table(predict = svmPred, truth = trainLabels)
       truth
predict   0   1   2   3   4   5   6   8
      0 125   0   0   0   0   0   0   5
      1   0   5   0   0   0   0   0   0
      2   0   0  18   0   0   0   0   0
      3   0   0   0  10   0   0   0   0
      4   0   0   0   0  24   0   0   0
      5   0   0   0   0   0   6   0   0
      6   0   0   0   0   0   0  12   0
      8   0   0   0   0   0   0   0   0
```
The confusion matrix for the test data shown below where a number of false negatives are shown particularly for patterns 2, 3, 5, and 8. This could indicate that the model is over-fitted or, as in the case of pattern 8, patterns have insufficient training data. Patterns 2 and 3 also use relatively few factors which likely increases the prediction error. The model will need to be refined as the dataset grows with additional training observations and its prediction performance is evaluated over time. 

```text
> ### test error of optimal svm model with clock as a predictor
> svmPred = predict(svmOpt, testData, probability = TRUE)
> table(predict = svmPred, truth = testLabels)
       truth
predict  0  1  2  3  4  5  6  8
      0 51  0  4  2  0  2  0  3
      1  0  2  0  0  0  0  0  0
      2  0  0  2  0  0  0  0  0
      3  1  0  0  6  0  0  0  0
      4  0  0  0  0 10  0  0  0
      5  0  0  0  0  0  5  0  0
      6  0  0  0  0  0  0  4  0
      8  0  0  0  0  0  0  0  0
```

R's summary function can be used to obtain some information about the SVM fit, the output is shown below. It can be seen that there is a large number of support vectors which indicates a complex decision boundary. This is also evident from the scatterplots above. 

```text
> summary(svmOpt)

Call:
svm(formula = y ~ ., data = trainData, kernel = "radial", gamma = svmTuneOut$best.model$gamma, 
    cost = svmTuneOut$best.model$cost, decision.values = FALSE, probability = TRUE, 
    scale = TRUE)

Parameters:
    SVM-Type: C-classification 
  SVM-Kernel: radial 
        cost: 100 
       gamma: 1 

Number of Support Vectors:  149

 ( 94 16 2 13 4 9 5 6 )

Number of Classes:  8 

Levels: 
 0 1 2 3 4 5 6 8
```

## Implementation
Now that the algorithm was selected, the next step was to implement the real-time prediction of patterns, develop an Alexa skill that performs voice tagging of training observations, and develop a method to periodically re-fit the SVM with new training data.

### Real-time Prediction and Action
A new thread called *predict()* was added to the [Raspberry Pi real-time software](https://github.com/goruck/all/blob/master/rpi/kprw-server.c) which runs periodically and sends sensor data to an R script via the *popen()* Linux system command to make a prediction. The prediction R script is found [here](https://github.com/goruck/all/blob/master/R/predsvm2.R). The thread reads the prediction from R, applies some confidence checking rules and does something if a true prediction is determined. Currently, various WeMo light switches in the house are controlled by the thread in response to predictions in a hardcoded manner but at some point a more flexible and extensible mapping of predictions to actions will be implemented (perhaps by use of another Alexa skill). The WeMo devices are controlled by a bash script called by a *system()* Linux system command in the thread. The WeMo bash script can be found [here](./scripts/wemo.sh). At some point the capability to automatically take action on a prediction will be added. This can be done by including the state of a WeMo switch as a factor in the model. Obviously, any device around the home that can be monitored and controlled through the LAN or Internet can be used as well.

Two models are used in the prediction R script, one that uses the clock as a prediction and one that does not. If both models predict the same pattern, the higher probability prediction is selected (in the case of both models making the same non-null prediction, a higher probability pattern from the model using clock as a predictor is likely a timed pattern that uses the clock). If one model has not identified any pattern and the other has, then the non-null case is selected.

The thread has the capability to log the output of the prediction R script which includes a timestamp, sensor states, and the prediction with probabilities. A sample from the log is below which correctly identifies the observation as being 'pattern 4' (slow walk from kid's rooms to playroom) with a higher probability that its a non-timed (i.e., not at any specific time of day) path. 

```text
********** New R Run (svm2) **********
timestamp: 2016-08-11T12:56:35Z 
 clock  za1 za16 za27 za28 za29 za30 za32
    12 -120  -56  -85  -74 -103   -1  -26
pred: 4 prob: .74 (w/o clk) | pred: 4 prob: .66 (w/clk)
********** End R Run (svm2) **********
```

There is also a rather naive approach implemented in the thread to predict the number of occupants in the house based on concurrent motion and door sensor activity. However it does provide reasonably accurate results based on subjective testing if there is enough motion in the house. The pattern predictions can probably be used to provide a more accurate occupancy estimate, that work is planned for a future rev of the code. 

The latency between sensor activity and prediction leading to the activation of a WeMo device is less than a second based on subjective testing. This is acceptable for now but as the dataset grows the model will become more complex (given its non-parametric nature) and so the latency will increase. There is also considerable latency added by using the R script via *popen()* since it adds its own overhead. Although using the R script accelerated overall development (since it was easy to reuse much of the R work from earlier stages in the project), at some point a C SVM library will probably be used in the thread instead of calling the R script in order to reduce latency. R itself uses a C/C++ library implementation of the popular *LIBSVM* package so it would be relatively straightforward to use it in the thread. More information on *LIBSVM* can be found [here](https://www.csie.ntu.edu.tw/~cjlin/libsvm/).

A simplified flowchart of the *predict()* thread operation is shown in the figure below.
predict

### Alexa Skill Support for Voice Tagging and Prediction
Firstly, an [AWS SimpleDB](https://aws.amazon.com/simpledb/) database was created to store the observations that the Alexa voice tagging skill generates. The database was created by the code shown below. This assumes that the AWS SDK has been installed on the machine. See [AWS SDK for JavaScript in Node.js](https://aws.amazon.com/sdk-for-node-js/) for how to do this.

```javascript
var AWS = require('/home/pi/nodejs/node_modules/aws-sdk');

var fs = require('fs');

AWS.config.region = 'us-west-2';

var simpledb = new AWS.SimpleDB({apiVersion: '2009-04-15'});

// create domain
var params = {
  DomainName: 'panelSimpledb' // required
};
simpledb.createDomain(params, function(err, data) {
  if (err) console.log(err, err.stack); // an error occurred
  else     console.log(data);           // successful response
});
```

The Alexa skill's schema and utterance database includes three speech intents, *OccupancyIsIntent*, *PredIsIntent*, and *TrainIsIntent*. This code can be found [here](https://github.com/goruck/all/tree/master/ask). When the user's speech triggers it, *OccupancyIsIntent* causes Alexa to return the occupancy prediction generated by the *predict()* thread as explained above, *PredIsIntent* causes Alexa to return the last true prediction, and *TrainIsIntent* associates a particular observation with a pattern using voice (i.e., voice tagging) and then stores it in SimpleDB.

The [Lambda Node.js code](https://github.com/goruck/all/tree/master/lambda) that services the Alexa speech intents includes three functions to support these intents. A function called [*trainInSession()*](https://github.com/goruck/all/blob/master/lambda/amzn/trainInSession.js) handles the *TrainIsIntent* intent, the function called *predInSession()* handles the *PredIsIntent* intent, and the function called *anyoneHomeInSession()*, handles the *OccupancyIsIntent* intent.

Currently, *TrainIsIntent* and *trainInSession()* uses 10 fixed patterns with the mapping to specific paths through the home as shown above. This forces the user to remember the mapping during training. Although acceptable for test purposes, a more flexible approach is required whereby the user is asked to provide the path name during training or is offered to select a path from a menu in case the path already exists. These enhancements will be added in a future revision of the skill.

The thread *msg_io()* in the [Raspberry Pi real-time software](https://github.com/goruck/all/blob/master/rpi/kprw-server.c) calculates the timestamped sensor data as described above and the Pi's server was returns that along with other information as JSON in response to a command from the Alexa skill running in AWS Lambda.

A simplified flow diagram of voice tagging using the *TrainIsIntent* and *trainInSession()* functionality is shown in the figure below.
train-flow-chart

A simplified flow diagram of getting a prediction using *predInSession()* and *PredIsIntent* functionality is shown in the figure below.
predict-flow-chart

### Model Retraining
The SVM models needs to be periodically refitted as new observations are taken, ground truth tagged by Alexa, and stored in SimpleDB. This is accomplished by a new Node.js routine locally on the Raspberry Pi that is run as a cron job every day at midnight. When the routine, [*simpledb-read.js*](https://github.com/goruck/all/blob/master/nodejs/simpledb-read.js), is run it reads SimpleDB and compares the latest observation with what was previously read. If there are new observation(s), the data is copied from SimpleDB and appended to a local copy and then the SVM models are refitted with it. The SVM model generation is done using R by a script called [*genSvmModels2.R*](https://github.com/goruck/all/blob/master/R/genSvmModels2.R) which is called from the Node.js routine. From that point forward, the updated models are used for real-time prediction in the *predict()* thread.

## Results
The model was trained using Alexa to voice tag observations for the patterns listed above. About ten true plus a few explicit false observations were required to get good accuracy prediction. The model was typically trained in the following way.

1. Walk the path through the house in a specific direction, approximate pace, and time (if applicable).
2. At the end of the path, tag the path with a pattern number by saying "Alexa, ask panel pattern n true", where n is the pattern number. 
3. Walk the path the opposite direction at the same pace.
4. At the end of the path, tag the path with a pattern number by saying "Alexa, ask panel pattern n false", where n is the pattern number. 

These steps were repeated about ten times. The pattern prediction will become bidirectional if steps 3 and 4 are omitted and in that case observations for the other patterns will form the false data for the specific pattern. It was important to end each pattern at a sensor boundary since data is input to the predictor when motion triggers a change in sensor output.

The model gets refitted with new data everyday at midnight, this process takes less than 2 minutes on the Raspberry Pi with the current dataset consuming about 85% of one of the Pi's CPU cores. 

At this time only subjective real-time prediction performance is available. This indicates less than one second of latency between the end of a path and the activation of a WeMo light. The prediction accuracy is very high (close to 100%) when the only motion in the house is the person walking the pattern. The accuracy degrades when there is other motion in the house at the same time a pattern is being walked as this makes the sensor data noisy. The accuracy degrades more quickly for the patterns that depend on relatively few factors which suggests that one way to make the system more robust is to increase the number of motion sensors in the house. Also, the patterns that use relatively few factors (e.g., #2) it proved infeasible to make them unidirectional given the sparse dataset.

# Development and Test environment
The Raspberry Pi was used headless throughout development and so ssh was used from another Linux machine to edit and debug the application code with gedit. The application code was compiled directly on the Raspberry Pi, given its small size it compiled quickly which obviated the need to setup a cross-compiler on a more capable machine.

Clients written in Node.js and C were used to test the server before integration with Lambda. This code is is in the goruck/all/test repo. 

The ASK and Lambda test tools available in the SDK and Lambda status information from AWS Cloudwatch Logs were used extensively during development and test.

Schematic entry and PCB layout was done using [KiCad](http://kicad-pcb.org/).

# Bill of materials and service cost considerations
The hardware bill of materials (BOM) total $85 and are as follows. This BOM is for the prototype version, the PCB version costs about the same. 

Item | Qty | Cost
-----|-----|-----
Raspberry Pi 2 Model B Quad-Core 900 MHz 1 GB RAM | 1 | $38
Various ICs and passives | 15 | $15
HighPi Raspberry Pi B+/2 Case | 1 | $14
32GB microSDHC | 1 | $12
JBtek® DIY Raspberry Pi 2 Model B Hat | 1 | $6
Totals | 19 | $85

The Lambda service cost will vary according to how often the Alexa skill is invoked and how much compute time the function consumes per month. A typical Lambda session for the alarm prototype lasted less than 450 ms with AWS typically billing me for 500 ms (they round up to the nearest 100 ms) and was allocated 128 MB memory. The free tier provides provides the first 400,000 GB-s processing and the first one million requests per month at no cost. At 128 MB the Alexa panel skill can use 3,200,000 seconds of free processing per month (6.2 million invocations of the skill) and the first 1 million invocations will be at **no cost**. AWS is truly built for scale. This assumes less than 1 GB per month external data is transfered to/from the Lambda function so that the Free tier is maintained.

See the [AWS website](https://aws.amazon.com/lambda/pricing/) for complete pricing information.

# Overall Hardware Design and Considerations
The interface circuit was first breadboarded and then moved to a prototyping board and later a custom design printed circuit board (PCB) that fits in an extended Raspberry Pi enclosure.

The prototyping board is from [JBtek®](http://smile.amazon.com/dp/B00WPFF9OA) and the enclosure is from [MODMYPI](http://www.modmypi.com/raspberry-pi/cases/highpi/highpi-raspberry-pi-b-plus2-case). The extended Pi enclosure also offers more height for components. However, there isn't a lot of area to fit the components; the interface circuit fit nicely but it would get increasingly difficult to fit additional components if required. There is height in the enclosure to stack another prototyping board but the component heights would have to be kept to a minimum. Photographs of the prototype are shown below.









Note: most components were salvaged from other projects and so the selection and placement is not optimized for either cost or size.

The prototype board was later replaced by a PCB that I designed in [kicad](http://www.kicad-pcb.org/) and had fabricated by [OSHPARK](https://oshpark.com/). All PCB design files are [here](./kgiu) A rendering of the front side of the PCB is shown below.

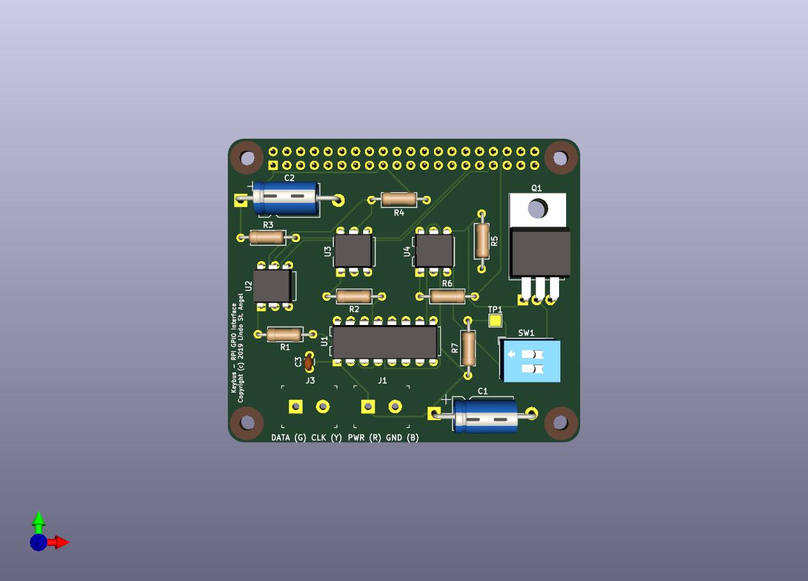
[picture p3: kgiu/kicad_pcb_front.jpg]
layout


Photograph of the PCB assembled in the Pi enclosure is shown below.

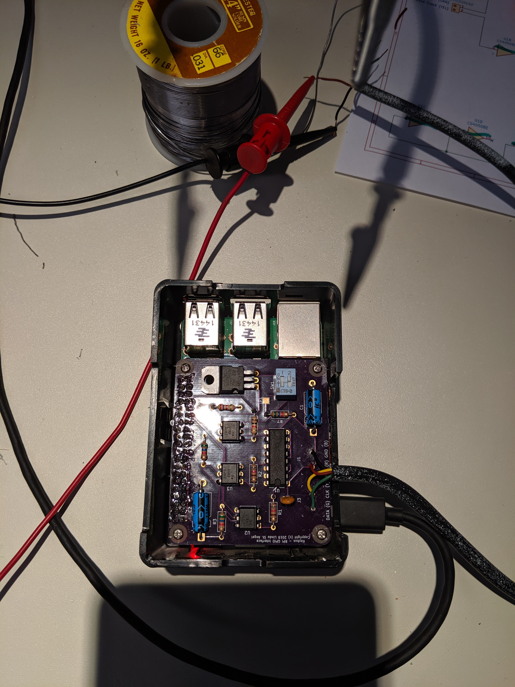
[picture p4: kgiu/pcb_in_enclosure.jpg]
pcb_in_enclosure


# Licensing
The ALL project is almost completely licensed under the [Apache License 2.0](http://choosealicense.com/licenses/apache-2.0/) unless otherwise specified in a LICENSE.txt file in a source code directory. The only exception is the code in the file [trainInSession.js](https://github.com/goruck/all/blob/master/lambda/amzn/trainInSession.js) and related documentation in this README which are licensed under the [Amazon Software License](https://aws.amazon.com/asl/).

# Contact Information
For questions or comments about the ALL project please contact the author goruck (Lindo St. Angel) at \{lindostangel\} AT \{gmail\} DOT \{com\}.

# Appendix

## DSC Power832 Overview
Technical manuals and general overview information about the Power832 can be found on [DSC's](http://www.dsc.com/index.php?n=library&o=view_documents&id=1) website.

## Proof of Concept Output to Terminal
screenshot from 2015-12-09 19 46 40
Note: connections to AWS Lambda triggered by Alexa

## Installed System Photo
installed system

## Early Proof of Concept Photo
proto pic1
proto pic2

## Original schematics with design notes
keybus-gpio-if1
keybus-gpio-if2

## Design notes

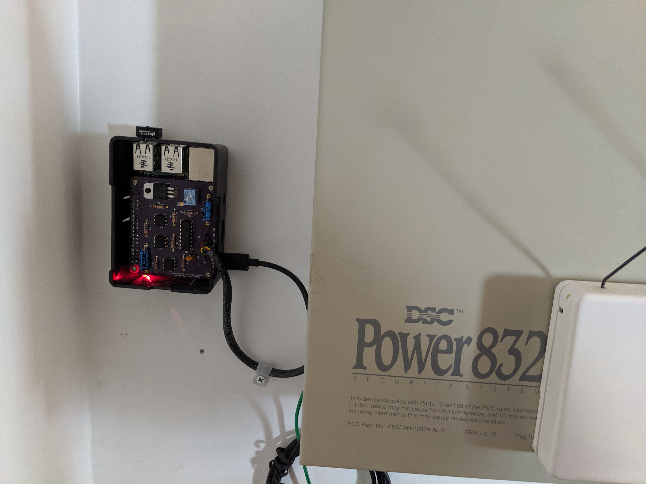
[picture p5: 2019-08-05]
kgiu/pcb_and_panel.jpg

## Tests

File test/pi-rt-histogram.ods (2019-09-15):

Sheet: pi2-rt-histogram
time | core1 | core2 | core3 | core4
0 | 0 | 0 | 0 | 0
1 | 0 | 0 | 0 | 0
2 | 0 | 0 | 0 | 0
3 | 0 | 0 | 0 | 0
4 | 0 | 0 | 0 | 0
5 | 0 | 0 | 0 | 0
6 | 0 | 0 | 0 | 0
7 | 0 | 0 | 0 | 0
8 | 0 | 0 | 0 | 0
9 | 0 | 0 | 0 | 0
10 | 0 | 0 | 0 | 0
11 | 0 | 0 | 0 | 0
12 | 0 | 25 | 0 | 54
13 | 1043 | 259 | 54 | 2700
14 | 369836 | 135495 | 78142 | 60649
15 | 2572379 | 2546711 | 1967071 | 2386112
16 | 1594075 | 2950975 | 5375480 | 2525569
17 | 701506 | 803221 | 1180473 | 539883
18 | 977133 | 529528 | 677474 | 2834081
19 | 6858243 | 4405172 | 1050293 | 19062009
20 | 11155011 | 14892162 | 16607724 | 9001559
21 | 2139515 | 2600553 | 6800145 | 1212930
22 | 520871 | 1459541 | 604194 | 889092
23 | 593100 | 2781452 | 1009761 | 1146038
24 | 710571 | 2279839 | 808481 | 877125
25 | 594371 | 1984780 | 828131 | 489724
26 | 530493 | 971156 | 599412 | 282303
27 | 290200 | 494535 | 351124 | 179012
28 | 517501 | 1070239 | 426420 | 542262
29 | 533727 | 1583991 | 1875764 | 1351096
30 | 836455 | 1336850 | 1812243 | 1087888
31 | 913885 | 1351062 | 1961249 | 446391
32 | 754295 | 398785 | 827923 | 175023
33 | 623999 | 389161 | 447306 | 261273
34 | 416385 | 494665 | 375984 | 688402
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

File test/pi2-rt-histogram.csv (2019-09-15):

time | core1 | core2 | core3 | core4
000000 | 000000 | 000000 | 000000 | 000000
000001 | 000000 | 000000 | 000000 | 000000
000002 | 000000 | 000000 | 000000 | 000000
000003 | 000000 | 000000 | 000000 | 000000
000004 | 000000 | 000000 | 000000 | 000000
000005 | 000000 | 000000 | 000000 | 000000
000006 | 000000 | 000000 | 000000 | 000000
000007 | 000000 | 000000 | 000000 | 000000
000008 | 000000 | 000000 | 000000 | 000000
000009 | 000000 | 000000 | 000000 | 000000
000010 | 000000 | 000000 | 000000 | 000000
000011 | 000000 | 000000 | 000000 | 000000
000012 | 000000 | 000025 | 000000 | 000054
000013 | 001043 | 000259 | 000054 | 002700
000014 | 369836 | 135495 | 078142 | 060649
000015 | 2572379 | 2546711 | 1967071 | 2386112
000016 | 1594075 | 2950975 | 5375480 | 2525569
000017 | 701506 | 803221 | 1180473 | 539883
000018 | 977133 | 529528 | 677474 | 2834081
000019 | 6858243 | 4405172 | 1050293 | 19062009
000020 | 11155011 | 14892162 | 16607724 | 9001559
000021 | 2139515 | 2600553 | 6800145 | 1212930
000022 | 520871 | 1459541 | 604194 | 889092
000023 | 593100 | 2781452 | 1009761 | 1146038
000024 | 710571 | 2279839 | 808481 | 877125
000025 | 594371 | 1984780 | 828131 | 489724
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

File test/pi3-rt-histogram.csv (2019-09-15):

time | core1 | core2 | core3 | core4
000000 | 000000 | 000000 | 000000 | 000000
000001 | 000000 | 000000 | 000000 | 000000
000002 | 000000 | 000000 | 000000 | 000000
000003 | 000000 | 000000 | 000000 | 000000
000004 | 000000 | 000000 | 000000 | 000000
000005 | 000000 | 000000 | 000000 | 000000
000006 | 000000 | 000000 | 000000 | 000000
000007 | 006168 | 009971 | 008192 | 013455
000008 | 355602 | 526107 | 190188 | 331921
000009 | 063335 | 111136 | 042071 | 043295
000010 | 1822331 | 173700 | 2775669 | 3025959
000011 | 774466 | 2598242 | 343001 | 215255
000012 | 081036 | 104545 | 026127 | 066261
000013 | 156312 | 105271 | 132842 | 105905
000014 | 033657 | 035614 | 073808 | 021474
000015 | 050826 | 051189 | 168543 | 077386
000016 | 048060 | 285382 | 218288 | 099070
000017 | 104273 | 160508 | 152354 | 106847
000018 | 044767 | 051166 | 062724 | 082359
000019 | 067641 | 044147 | 074712 | 053278
000020 | 078035 | 045808 | 071924 | 053486
000021 | 205210 | 019201 | 278393 | 392641
000022 | 137433 | 247769 | 109246 | 057175
000023 | 043873 | 090992 | 023704 | 018773
000024 | 223058 | 027318 | 010815 | 009277
000025 | 085098 | 018499 | 014807 | 007768
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

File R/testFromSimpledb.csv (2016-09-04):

clock | sample | za1 | za2 | za3 | za4 | za5 | za6 | za7 | za8 | za9 | za10 | za11 | za12 | za13 | za14 | za15 | za16 | za17 | za18 | za19 | za20 | za21 | za22 | za23 | za24 | za25 | za26 | za27 | za28 | za29 | za30 | za31 | za32 | zd1 | zd2 | zd3 | zd4 | zd5 | zd6 | zd7 | zd8 | zd9 | zd10 | zd11 | zd12 | zd13 | zd14 | zd15 | zd16 | zd17 | zd18 | zd19 | zd20 | zd21 | zd22 | zd23 | zd24 | zd25 | zd26
2016-05-15T13:00:21.747Z | 552635 | -45440 | -552635 | -552635 | -552635 | -552635 | -552635 | -552635 | -552635 | -552635 | -552635 | -552635 | -552635 | -552635 | -552635 | -552635 | -1105 | -552635 | -552635 | -552635 | -552635 | -552635 | -552635 | -552635 | -552635 | -138107 | -35877 | -8529 | -1111 | -6931 | -155 | -552635 | -1079 | -45429 | -552635 | -552635 | -552635 | -552635 | -552635 | -552635 | -552635 | -552635 | -552635 | -552635 | -552635 | -552635 | -552635 | -552635 | -1100 | -552635 | -552635 | -552635 | -552635 | -552635 | -552635 | -552635 | -552635 | -131262 | -35828
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

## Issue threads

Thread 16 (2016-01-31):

add checks if running with su priv and raspberry pi 2 hw in kprw-server.c

goruck, 2016-01-31:
Add checks if running with su priv and raspberry pi 2 hw in kprw-server.c. Code won't run otherwise, so its good to throw an error if user tries.

goruck, 2016-12-25:
Check for Raspberry pi 2 should be done at compile time. Does not seem to be worth adding a make file to check this, so just fixed the check if user is running the program as root.

Closed 2016-12-25.

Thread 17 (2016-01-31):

add friendly name for zone info

goruck, 2016-01-31:
Currently, generic zone information is broadcasted by Alexa when user asks for a status update. Friendly names (e.g., "front door open" instead of "zone 1, 1 not ready") would be much more useable. This should probably be implemented as a look-up table in all.js in the lambda function for the most general and scalable solution.

goruck, 2016-02-28:
resolved in commit a345d309a2878948ef67ba01d3a0d8cf5cd67fab

Closed 2016-02-28.

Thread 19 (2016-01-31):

change interaction model to terminate after arm intent

goruck, 2016-01-31:
Right now after an arm intent ('stay' or 'away'), Alexa stays in the session. The only way to terminate a session normally is with a 'status' command. This should be changed in all.js so that the session ends after a successful arm intent is processed.

goruck, 2016-02-07:
Fixed for both arm intent as well as other keypad inputs and pin input. Now session ends after any command.

Closed 2016-02-07.

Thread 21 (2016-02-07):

ask panel for anything triggeres status intent

goruck, 2016-02-07:
The voice interface is designed to give the user a system status update when saying, for example, “Alexa, ask Panel for status”. However, asking Panel anything, for example, “Alexa, ask Panel for nothing” will also trigger the same intent.

goruck, 2016-03-12:
resolved by adding voice utterances to ask model that improved recognition

Closed 2016-03-12.

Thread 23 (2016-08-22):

waitCLKchange

rogueturnip, 2016-08-22:
Is waitCLKchange still used?  I can't find any reference to the function other then it's definition.  I know that this was used in the arduino code for DSC communication so wanted to find out if it's used here and if not what was the reason for removing it.

goruck, 2016-09-05:
waitCLKchange is not used. Its not required since waiting for the clock to change is done as part of the while(1) loop in the panel_io thread. The function ts_diff is used to measure time between clock events in the thread which is used to differentiate data bits from word boundaries. I'll remove the waitCLKchange function to avoid confusion. Please let me know if that clears things up and I'll close the issue. If not, let me know what else you need. Thanks.

rogueturnip, 2016-09-05:
Thanks very much.  this is what I had figured when I kept going over the code.  I was porting the concept over to an Arduino because it's lower power needs and I wanted to be able to drive it using the power from the panel.  Just waiting for my optoisolators to arrive so I can start writing to the keybus.

Really like the work you are doing with ML.  I was contemplating the same thing.

Great work!

goruck, 2016-09-11:
Thanks! Hope your port to Arduino goes well, take care to observe proper voltages and impedances on the Keybus since you don't want to damage your panel. Hopefully the info on ALL helped, let me know if you have any more questions.

Closed 2016-09-11.

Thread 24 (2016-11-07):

beaglebone black

rogueturnip, 2016-11-07:
Do you see any reason that this wouldn't work on a beaglebone black with just changes to the pins?

goruck, 2016-11-11:
Might be hard. Looks like it uses the TI AM335x single core processor. The raspberry pi real time code assumes a quad core processor and one core is dedicated to the fast real time routines needed to service the signals coming off the DSC's keybus. The other cores are used to run everything else. You may find that trying to run everything on a single core will result in higher priority kernel code preempting the code servicing the keybus. You'd also have to change the memory address that access the gpio registers, this is implementation dependent and probably could be found in the TI documentation for the chip. tldr: Trying to get this to run on a single core might be more trouble than it's worth. Let me know if this makes sense. Happy to elaborate more.

rogueturnip, 2016-11-15:
Thanks!  That makes perfect sense.  Am I right to guess that if I only did the DSC keybus activity (removed the ML portion) then it might work on the beaglebone.

goruck, 2016-11-18:
I think you'll likely see issues even if you remove the ML code. In fact,
you don't have to remove the ML code just make sure the thread running the
fast I/O processing runs at the highest priority in the C program (but not
at level 99 which would preempt the kernel). I found that i had to isolate
the I/O processing on its own core to ensure proper real time performance
otherwise I got bit errors accessing the key bus. Try it, it might work on
your system as long as you're running a RT Linux. I'd be really interested
in the results.

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

rogueturnip, 2016-11-18:
That makes sense. What I'm trying is moving then Io processing to an atmel
mcu and pass decoded commands over the UART to an openwrt mips board.

On Thu, Nov 17, 2016, 5:48 PM Lindo St. Angel <notifications@github.com>
wrote:

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

goruck, 2016-11-19:
Yep, good solution. I like that architecture but decided to go the real time Linux route on a single raspberry pi to simply the hardware. This allows the ability to process both fast real time and use the full power of Linux on a single raspberry pi. Downside is software complexity and dealing with the intricacies of real time Linux. Good luck. I'll close this issue but always happy to help. Send me a link to your code sometime.

Closed 2016-11-19.

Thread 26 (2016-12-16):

resistor values

rogueturnip, 2016-12-16:
I was building out the circuit and discovered that my CLK and DTA only run at 8V (others on forums say 7V-10V is normal).  Looking into this I think the value of 1.2kOhm is too large and your Forward Current isn't going to be big enough for the optocoupler to function (4N25 needs 10mA).

It might be worth to add to your documentation how to calculate the resister values dependent on the input voltages.  The other option would just be to size the resistors to something like 500Ohms because that would still be fine even if the voltage on CLK and DTA was 13V.

Of course that's only deals with the one resistor.  The other side of the optocoupler needs to be calculated too.

Please correct me if I'm wrong, it's been quite a few years since my circuit days.

goruck, 2016-12-17:
Thanks for opening the issue.

You're right. I really don't know the tolerance on the Keybus voltages. The DSC Power832 PC5015 Installation Manual only states that all System Outputs (including the Keybus) voltages are 12 VDC @550 mA (all outputs in total cannot exceed 550 mA). Based on my experience a reasonable voltage tolerance on a regulator is +/- 10% which translates to 13.2 V to 10.8 V. My system is at the high end of that range. Your value of 8 V sounds really low, are you sure that you are not trying to source more than 550 mA from the system outputs? If so that would cause the system outputs to drop below the minimum regulated voltage. Also, what DSC panel model do you have? Maybe your model has difference specs.

Getting to your question, yes you would use a smaller resistor if the Keybus voltage was lower as calculated by R = V / I, where V is the min Keybus voltage and I is the Opto min current. I would not go too low on the resistor however because you want to keep the current drawn from the keybus lines as low as possible because the keypads and possibly expansion modules draw their own fair share of current. And the system runs off a battery during power outages, you want that battery to last as long as possible. You might want to sum up all the devices (keypads, expansion modules, etc) in you system (including the Optoisolators) to make sure you are not drawing more than 550 mA. Also, if you can, look at the keybus signals using an oscilloscope. You may be able to see the voltage drooping between signal transitions which could indicate too much current is being drawn.

I will update the documentation to reflect the nominal voltage of the keybus is 12 V and that some people have reported much lower system output voltages and so the values of the Optoisolator current limiting resistors may have to be adjusted.

Let me know what you find out and if you have any other questions / concerns.

rogueturnip, 2016-12-17:
Excellent! I was on the right track.  I'm running a PC1832 main panel so maybe things are different.  I'm pretty sure i"m not pulling that much current.  My setup is based on a few parts I had so it's only a keypad (RFK5501 with wireless), motion sensor, 1 wireless sensor, and 2 hard wired sensors.  I pulled up the scope images I took when I started playing with this and both the CLK and DTA have amplitudes of 6.5V.  The actual power off the panel runs solidly at 13.5V.

I started wondering if a level shifter from a N-Channel Transistor might be another way to do a drop in the voltage or rise for the writing (my next task to tackle).

goruck, 2016-12-17:
I just realized that you must not be using the CD4010 buffers (see schematic) between the keybus clock and data lines and the optoisolators and instead are trying to drive them directly through a current limiting resistor. I highly recommend that you do not drive the optoisolators directly from the panel because you can essentially drive the optoisolators much harder and therefore get better signal integrity without having to worry about drawing too much from the panel. I think using the CD4010 buffers are easier than designing a discrete buffer from a transistor per your comment, but that's largely an implementation decision. Either can work.

You should make sure that you are measuring the clock and data voltages unloaded, I.e., with the optoisolators not connected to rule out them drawing too much current. Also measure the voltage drop across the resistor with a scope to find out how much current is actually being drawn from the keybus. I'm suspecting that you are drawing too much current because the clock and data peak voltages should be the same as the main supply (on the Red keybus wire). Given your main supply is ~13 V, the clock and data should be too.

rogueturnip, 2016-12-17:
I thought the CD4010 was suppose to boost my DTA and CLK and it was odd when I wasn't seeing this.  My layout does have this in it too.  I wonder if I've wired it up incorrectly.  I didn't put the grounding wires to the unused input pins so I'll so that and I also didn't put a capacitor from pin 16 to 8.

rogueturnip, 2016-12-17:
I noticed that on the output side of the CD4010 I'm only getting about 7.5V on CLK and 10V on DTA. This seems odd to me.

rogueturnip, 2016-12-17:
Thought I'd mention, I dropped in https://www.sparkfun.com/products/12009 instead of using the optocouplers and it's working.  I cabled the panel power to HV and the Arduino Uno to LV.   It appears the current draw is very low so that's good for the solution too.  Right now I'm only reading from the panel so my next test is doing the write side of things through this solution.

goruck, 2016-12-17:
Regarding the [CD4010](https://www.circuitspecialists.com/content/75613/cd4010.pdf), make sure that you have both VCC and VDD connected to the Keybus +12 V supply (RED wire). Sounds like you might have a wiring error or a bad part. Its always good practice to use bypass caps and tie off unused inputs on logic devices otherwise you risk oscillation or badly ringing circuits. That logic level converter board form sparkfun should work fine in place of the CD4010 but of course your data and clock will not be inverted from the Keybus to the processor like it is for me.

rogueturnip, 2016-12-18:
Looks like I might have a bad cd4010 and it was my only one.  The level shifter from sparkfun seems to work well replacing the cd4010 and the optocouplers.

Thanks for giving me feedback on things, it's been very helpful.

goruck, 2016-12-18:
No problem, your approach will function but might not be 100% reliable. You might want to think about still using the optoisolator with that sparkfun [buffer](http://cdn.sparkfun.com/datasheets/BreakoutBoards/BSS138.pdf) driving it, this will allow you to electrically isolate the grounds between the two systems. Isolating grounds is a good design practice and will typically result in a more robust system wrt noise and will avoid creating [ground loops](http://www.miinet.com/Portals/0/PDFs/Signal_Isolators_Converters_and_Interfaces_The_Ins_and_Outs_Interactive_White_Paper_Moore_Industries.pdf). I'll close the issue. Thanks.

Closed 2016-12-18.

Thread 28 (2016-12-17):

AWS IoT

rogueturnip, 2016-12-17:
Not really an issue but more of a question.  Is your solution not using AWS IoT because it wasn't available at the time?  It seems to me that you could leverage the AWS IoT to get the data into SimpleDB and the Alexa Lambda.  If the messages were all passed as MQTT Topics could that simplify the thread logic too?

goruck, 2016-12-20:
Its a good question. I really haven't looked at AWS IoT services in detail but it was available at the time I designed the system to use Alexa to train a machine learning algorithm. I suspect that using the AWS IoT services would result in a much more scalable solution then what I've done. My main motivation was really to prove that I could use Alexa to train ML based on motion sensor data, not so much making it scalable. I would like to start a project that uses AWS IoT to learn it. That may be next.

goruck, 2016-12-24:
Labeling this as a question and closing.

Closed 2016-12-24.

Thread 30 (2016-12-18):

Arming for Polly the dog at home is broken.

goruck, 2016-12-18:
Looks like a logic error in all.js now that the new code to ignore the motion sensors is in place.

Closed 2016-12-19.

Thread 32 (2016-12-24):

socket error will return empty string confusing functions in all.js

goruck, 2016-12-24:
If there is a socket error getPanelStatus will return an empty string which will confuse functions in all.js, sometimes returning an invalid response to the user. Any function that calls getPanelStatus should check for an empty string in its response and throw a voice error to the user.

Closed 2016-12-25.

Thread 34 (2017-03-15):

Stay command not recognized

goruck, 2017-03-15:
The stay command is not longer recognized as being valid.

goruck, 2017-03-27:
Can not reproduce. Could have been an Alexa side ASR issue.

rogueturnip, 2017-03-27:
I might have something for you to look at.

Occasionally the panel will send out a 0x05 status message but the next octet contains a 93 or 1.  If you log this and then the keypad data the other keypads respond to this.  So if you happen to transmit at the same time as the other keypads are responding you won't get a successful message across.  This happens for other button presses too.

On normal 0x05 messages the keypad just keeps sending FFFF so you can send key strokes fine.  It appears that if the second octet can't be decoded then you have to pause on a send because you might have another keypad responding.

goruck, 2017-03-28:
Hey, thanks for the info.

First of all, I am reopening the issue since I'm able to repro it 100% using Alexa on FireTV but not on Echo, Dot, or Tap. This seems to be an Alexa ASR issue that's unique to FireTV. I'll contact Amazon on this.

Now, regarding your excellent observation!

You are right about these commands from the panel for keypad queries and potential collisions with writes from ALL to the panel. In the V1 code I handled this in the panel_io thread, detecting that condition and reissuing the write. However, I found that the panel issued other keypad query commands as well which complicated the logic and made me nervous that I was missing other corner cases. However, I found that when the keypads respond to panel queries they do so with a very short message (< 20 bits). So in the V2 code I added the following in the panel_io thread to detect the condition and repeat the write:

```C
if (bit_cnt < 20) {
  fprintf(stderr, "panel_io: bit count < 20 (%i)! Repeating panel writes and ignoring reads.\n", bit_cnt);
  } else {
    res = pushElement1(word, MAX_BITS); // store panel-> keypad data
    if (res != MAX_BITS) {
      fprintf(stderr, "panel_io: fifo write error\n"); // record error and continue
    }

    res = pushElement1(wordkr, MAX_BITS); // store keypad-> panel data
    if (res != MAX_BITS) {
      fprintf(stderr, "panel_io: fifo write error\n");
    }

    res = popElement2(wordkw, MAX_BITS); // get a keypad command to send to panel
    if (res != MAX_BITS) { // fifo is empty so output idle instead of repeating previous
      strncpy(wordkw, IDLE, MAX_BITS);
    }
}
```

This has proven very robust and I have not seen a case where ALL fails to write to the panel.

rogueturnip, 2017-03-28:
Thanks for pointing that out.  That is a nice clean simple way to handle it.  The approach we were taking was to capture all the query type messages and respond as if we were a keypad.  I have a couple of keypad configured and can disconnect them to find out if the response is slot dependent.  For 0x11 it is but still decoding the other ones.  Didn't expect to see query type message in the 0x05.

If you respond to the 0x11 message the slot you respond as starts showing up as a registered keypad in the other keypads when you do a *8 IC 903.

Hoping in the next couple of days to have some decoded messages passed across into nodejs and then AWS IoT into DynamoDB.

goruck, 2017-04-01:
The root cause of this issue was that the Alexa ASR (automatic Speech Recognition) returned the case of the value inconsistently across Amazon Alexa enabled devices. Amazon has since corrected this defect and now Alexa ASR returns lower case values across its devices. However, Amazon offers no guarantee what the case will be, only that  it will be consistent across devices. Therefore to be safe, the Lambda code now forces a conversion to lower case on all Alexa ASR returned values before the value is used.

Closed 2017-04-01.

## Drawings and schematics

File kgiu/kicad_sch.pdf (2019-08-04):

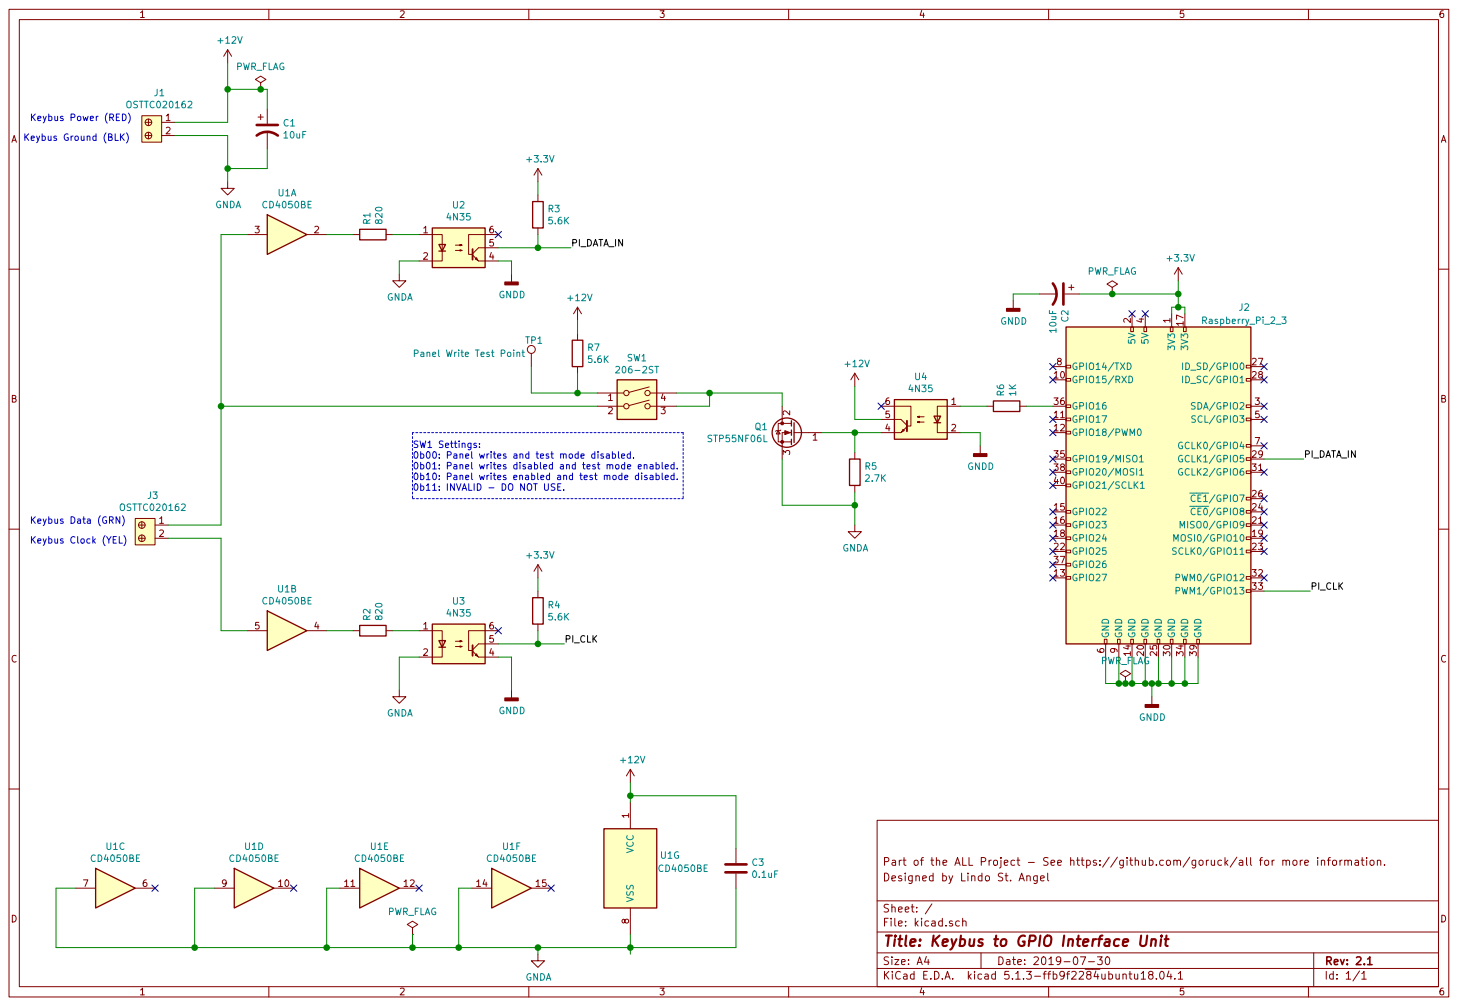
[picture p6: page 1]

SW1 Settings: 0b00: Panel writes and test mode disabled. 0b01: Panel writes disabled and test mode enabled. 0b10: Panel writes enabled and test mode disabled. 0b11: INVALID - DO NOT USE.

Part of the ALL Project - See https://github.com/goruck/all for more information.
Id: 1/1 Title: Keybus to GPIO Interface Unit File: kicad.sch Sheet: / Designed by Lindo St. Angel

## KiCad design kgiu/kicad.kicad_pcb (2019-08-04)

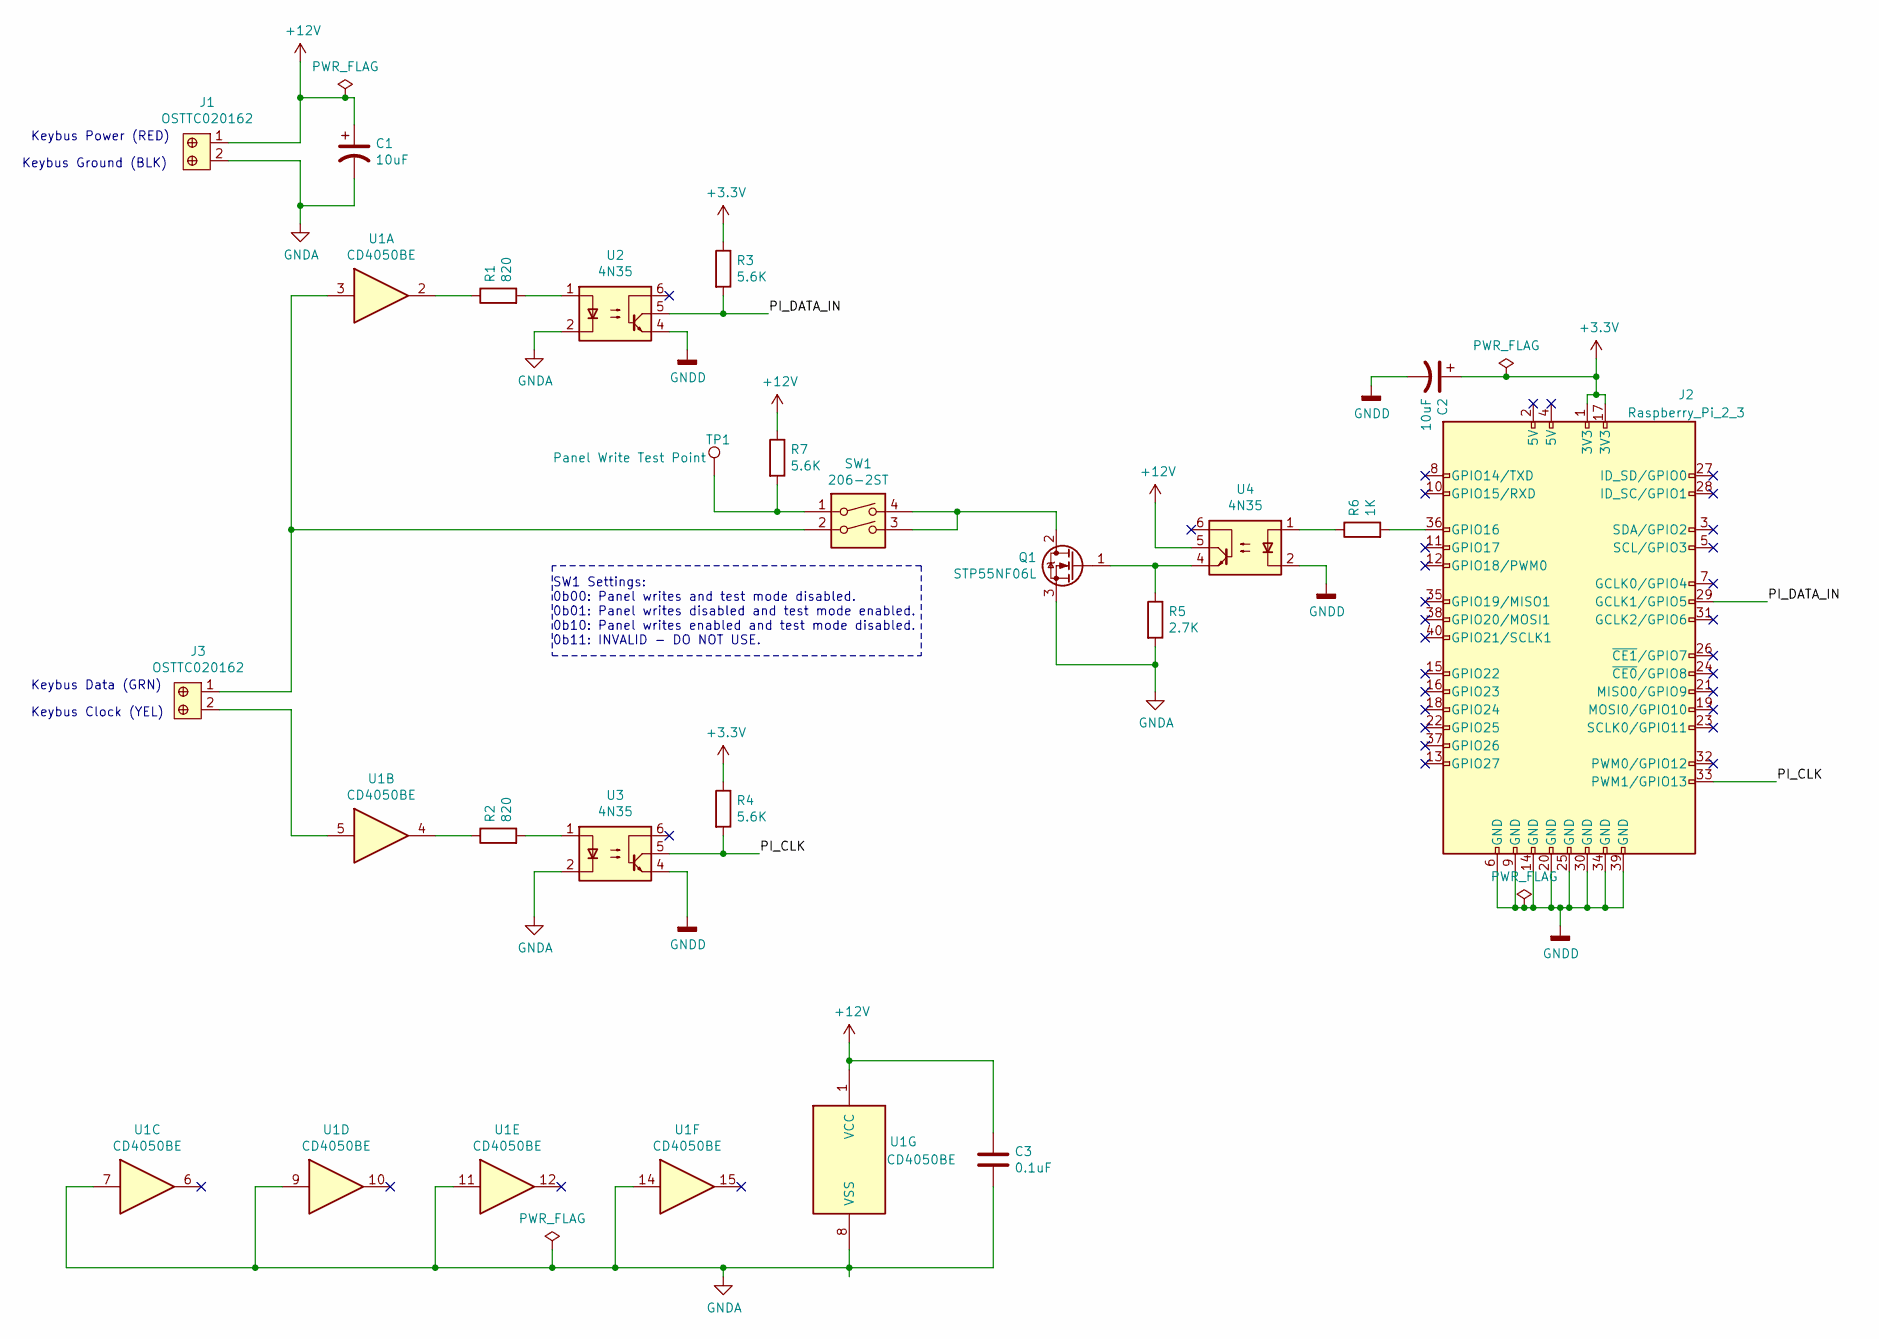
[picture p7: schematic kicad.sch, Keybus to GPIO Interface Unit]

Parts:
C1, C2: 10uF; CP_Axial_L11.0mm_D6.0mm_P18.00mm_Horizontal; MPN 106TTA035MSD
C3: 0.1uF; C_Disc_D3.0mm_W1.6mm_P2.50mm; MPN K104K15X7RF5TL2; Digi-Key-PN BC1084CT-ND
J1, J3: OSTTC020162; Term_Block_1x2_P5mm; MPN OSTTC020162; Digi-Key_PN ED2600-ND
J2: Raspberry_Pi_2_3; PinSocket_2x20_P2.54mm_Vertical; Digi-Key-PN S6104-ND
Q1: STP55NF06L; TO-220-3_Horizontal_TabDown; Digi-Key-PN 497-6742-5-ND
R1, R2: 820; R_Axial_DIN0207_L6.3mm_D2.5mm_P10.16mm_Horizontal; Digi-Key-PN CF14JT820RCT-ND
R3, R4, R7: 5.6K; R_Axial_DIN0207_L6.3mm_D2.5mm_P10.16mm_Horizontal; Digi-Key-PN CF14JT5K60CT-ND
R5: 2.7K; R_Axial_DIN0207_L6.3mm_D2.5mm_P10.16mm_Horizontal; Digi-Key-PN CF14JT2K70CT-ND
R6: 1K; R_Axial_DIN0207_L6.3mm_D2.5mm_P10.16mm_Horizontal; Digi-Key-PN CF14JT1K00CT-ND
SW1: 206-2ST; SW_DIP_SPSTx02_Slide_9.78x7.26mm_W7.62mm_P2.54mm; MPN 206-2ST; Digi-Key-PN CT2062ST-ND
TP1: Panel Write Test Point; TestPoint_Pad_2.0x2.0mm
U1: CD4050BE; DIP-16_W7.62mm; MPN CD4050BE; Digi-Key-PN 296-2056-ND
U2, U3, U4: 4N35; DIP-6_W7.62mm; MPN 4N35; Digi-Key_PN 160-1304-5-ND

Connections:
+3V3: C2.1, J2.1 (3V3), J2.17 (3V3), R3.1, R4.1
+12V: C1.1, C3.1, J1.1, R7.1, U1.1 (VCC), U4.5
/PI_CLK: J2.33 (PWM1/GPIO13), R4.2, U3.5
/PI_DATA_IN: J2.29 (GCLK1/GPIO5), R3.2, U2.5
GNDA: C1.2, C3.2, J1.2, Q1.3 (S), R5.2, U1.7, U1.8 (VSS), U1.9, U1.11, U1.14, U2.2, U3.2
GNDD: C2.2, J2.6 (GND), J2.9 (GND), J2.14 (GND), J2.20 (GND), J2.25 (GND), J2.30 (GND), J2.34 (GND), J2.39 (GND), U2.4, U3.4, U4.2
unnamed: J2.36 (GPIO16), R6.2
unnamed: J3.1, SW1.2, U1.3
unnamed: J3.2, U1.5
unnamed: Q1.1 (G), R5.1, U4.4
unnamed: Q1.2 (D), SW1.3, SW1.4
unnamed: R1.1, U1.2
unnamed: R1.2, U2.1
unnamed: R2.1, U1.4
unnamed: R2.2, U3.1
unnamed: R6.1, U4.1
unnamed: R7.2, SW1.1, TP1.1

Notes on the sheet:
Keybus Power (RED)
Keybus Ground (BLK)
Keybus Clock (YEL)
Keybus Data (GRN)
SW1 Settings: 0b00: Panel writes and test mode disabled. 0b01: Panel writes disabled and test mode enabled. 0b10: Panel writes enabled and test mode disabled. 0b11: INVALID - DO NOT USE.

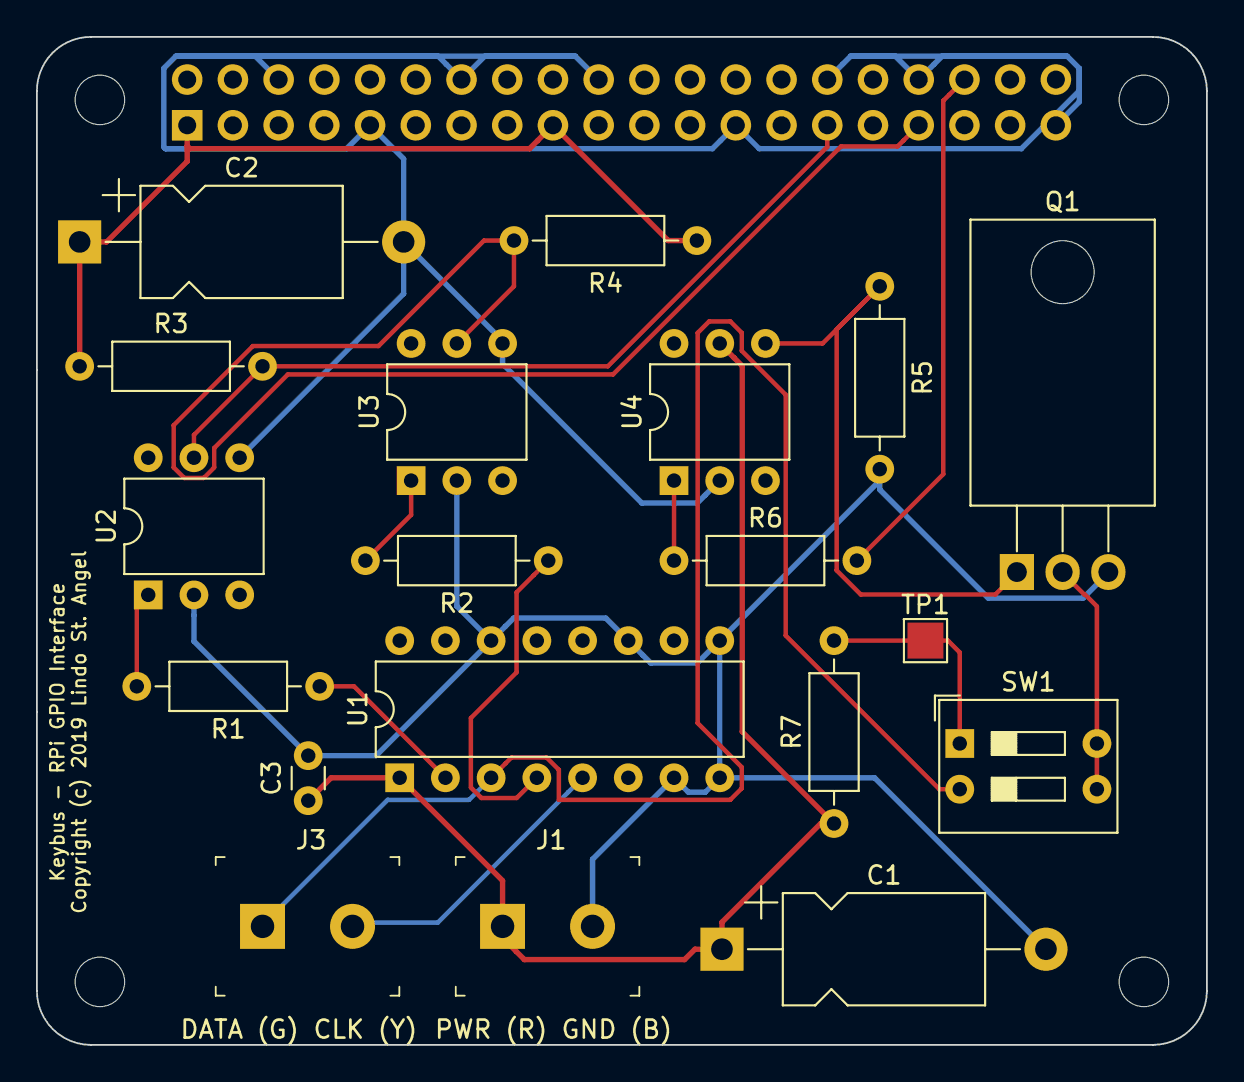
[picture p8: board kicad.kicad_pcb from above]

Board: 2 copper layers, 65.0 x 56.0 mm, 20 parts (1 on the bottom side), 17 nets.

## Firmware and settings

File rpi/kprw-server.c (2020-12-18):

/*
 *
 * kprw-server.c, V2.1
 *
 * Emulates a DSC Power832 keypad controller. Reads and writes over the keybus are supported.
 *
 * This version supports machine learning via R.
 *
 * Compile with "gcc -Wall -o kprw-server kprw-server.c -lrt -lpthread -lwrap -lssl -lcrypto".
 * To enable R logging, add -DRLOG=\"/home/pi/all/R/rlog.txt\" (change path as required).
 * To output status messages to stdout, add -DVERBOSE.
 * To run a real-time safe test at start of program, add -DTESTRT.
 *
 * Tested with:
 *  Raspberry Pi 2 and Raspbian Wheezy + PREEMPT_RT patched kernel 3.18.9-rt5-v7.
 *  Raspberry Pi 3 and Raspbian Buster + PREEMPT-RT patched kernel 4.19.59-rt23-v7+.
 *
 * Must run under linux a Linux PREEMPT_RT patched kernel and as su.
 *
 * See https://github.com/goruck/all for details.
 *
 * Copyright (c) 2016 - 2019 by Lindo St. Angel.
 *
 */

#define _GNU_SOURCE // Need to use some non-portable pthread functions

#include <stdio.h>
#include <stdlib.h>
#include <fcntl.h>		// Needed for file I/O
#include <sys/mman.h>		// Needed for mlockall()
#include <unistd.h>
#include <stdint.h>
#include <sched.h>
#include <string.h>
#include <time.h> 		// Needed for getrusage()
#include <sys/resource.h>	// Needed for getrusage()
#include <pthread.h>
#include <sys/utsname.h>
#include <ctype.h>		// Needed for isdigit()
#include <malloc.h>		// Needed for mallopt()

// socket
#include <sys/socket.h>
#include <netinet/in.h>
#include <arpa/inet.h>
#include <signal.h>
#include <tcpd.h> //for hosts_ctl()
#include <netdb.h>
#define	BUF_LEN		16  // size of string to hold longest message incl '\n'
#define BACKLOG		1   // only allow one client to connect
//#define	_BSD_SOURCE // to get definitions of NI_MAXHOST and NI_MAXSERV from <netdb.h>
#define ADDRSTRLEN	(NI_MAXHOST + NI_MAXSERV + 10)

// openssl
#include <openssl/ssl.h>
#include <openssl/err.h>
#include <openssl/evp.h>

// GPIO Access from ARM Running Linux. Based on Dom and Gert rev 15-feb-13
#define BCM_PERI_BASE 0x3F000000 // modified for Pi 2/3
#define GPIO_BASE     (BCM_PERI_BASE + 0x200000) // GPIO controller
#define BLOCK_SIZE    (4*1024) // size of memory for direct gpio access

// GPIO setup macros. Always use INP_GPIO(x) before using OUT_GPIO(x) or SET_GPIO_ALT(x,y).
#define INP_GPIO(g) *(gpio+((g)/10)) &= ~(7<<(((g)%10)*3))
#define OUT_GPIO(g) *(gpio+((g)/10)) |=  (1<<(((g)%10)*3))
#define SET_GPIO_ALT(g,a) *(gpio+(((g)/10))) |= (((a)<=3?(a)+4:(a)==4?3:2)<<(((g)%10)*3))
#define GPIO_SET *(gpio+7)  // sets bit by writing a 1, writing a 0 has no effect (BCM Set 0)
#define GPIO_CLR *(gpio+10) // clears bits which are 1 ignores bits which are 0 (BCM Clear 0)
#define GET_GPIO(g) (*(gpio+13)&(1<<g)) // 0 if LOW, (1<<g) if HIGH (BCM Level 0)
#define GPIO_EVENT *(gpio+16) // 0 if no event, (1<<g) if event (BCM Event Detect Status 0)
#define ENB_GPIO_REDGE *(gpio+19) //Rising Edge Detect Enable 0
#define ENB_GPIO_FEDGE *(gpio+22) //Falling Edge Detect Enable
#define ENB_GPIO_HIDET *(gpio+25) //High Detect Enable 0
#define ENB_GPIO_LODET *(gpio+28) //Low Detect Enable 0
#define GPIO_PULL *(gpio+37) // Pull up/pull down
#define GPIO_PULLCLK0 *(gpio+38) // Pull up/pull down clock (BCM Clock 0)

// GPIO pin mapping.
#define PI_CLOCK_IN	(13) // BRCM GPIO13 / PI J8 Pin 33
#define PI_DATA_IN	(5)  // BRCM GPIO05 / PI J8 Pin 29
#define PI_DATA_OUT	(16) // BRCM GPIO16 / PI J8 Pin 36

// GPIO high and low level mapping macros.
#define PI_CLOCK_HI (1<<PI_CLOCK_IN)
#define PI_CLOCK_LO (0)
#define PI_DATA_HI  (1<<PI_DATA_IN)
#define PI_DATA_LO  (0)

// GPIO invert macro
#define INV(g,s)	((1<<g) - s)

// real-time
#define MAIN_PRI       (70) // main thread priority
#define MSG_IO_PRI     (70) // message io thread priority
#define PREDICT_PRI    (50) // predict thread priority
#define PANEL_IO_PRI   (90) // panel io thread priority - panel io pri must be highest
#define MAX_SAFE_STACK (32*1024*1024) // 32MB pagefault free buffer
#define MY_STACK_SIZE  (100*1024) // 100KB thread stack size

// panel i/o thread
#define NSEC_PER_SEC   (1000000000LU) // 1 second.
#define INTERVAL       (100*1000) // 100 us timeslice.
#define CLK_PER        (1000000L) // 1 ms clock period.
#define HALF_CLK_PER   (500000L) // 0.5 ms half clock period.
#define SAMPLE_OFFSET  (120000L) // 0.12 ms sample offset from clk edge for panel read
#define KSAMPLE_OFFSET (300000L) // 0.30 ms sample offset from clk edge for keypad read
#define HOLD_DATA      (220000L) // 0.22 ms data hold time from clk edge for keypad write
#define CLK_BLANK      (5000000L) // 5 ms min clock blank.
#define NEW_WORD_VALID (2500000L) // if a bit arrives > 2.5 ms after last one, declare start of new word.
#define MAX_BITS       (64) // max 64-bit word read from panel
#define MAX_DATA       (1*1024) // 1 KB data buffer of 64-bit data words - ~66 seconds @ 1 kHz.
#define FIFO_SIZE      (MAX_BITS*MAX_DATA) // FIFO depth

// keypad button bit mappings
// no button:	0xff 0xff 0xff 0xff 0xff 0xff 0xff 0xff
#define IDLE	"1111111111111111111111111111111111111111111111111111111111111111"
// *:		0xff 0x94 0x7f 0xff 0xff 0xff 0xff 0xff
#define STAR	"1111111110010100011111111111111111111111111111111111111111111111"
// #:		0xff 0x96 0xff 0xff 0xff 0xff 0xff 0xff
#define POUND	"1111111110010110111111111111111111111111111111111111111111111111"
// 0:		0xff 0x80 0x7f 0xff 0xff 0xff 0xff 0xff
#define ZERO	"1111111110000000011111111111111111111111111111111111111111111111"
// 1:		0xff 0x82 0xff 0xff 0xff 0xff 0xff 0xff
#define ONE	"1111111110000010111111111111111111111111111111111111111111111111"
// 2:		0xff 0x85 0x7f 0xff 0xff 0xff 0xff 0xff
#define TWO	"1111111110000101011111111111111111111111111111111111111111111111"
// 3:		0xff 0x87 0xff 0xff 0xff 0xff 0xff 0xff
#define THREE	"1111111110000111011111111111111111111111111111111111111111111111"
// 4: 		0xff 0x88 0xff 0xff 0xff 0xff 0xff 0xff
#define FOUR	"1111111110001000111111111111111111111111111111111111111111111111"
// 5: 		0xff 0x8b 0x7f 0xff 0xff 0xff 0xff 0xff
#define FIVE	"1111111110001011100011111111111111111111111111111111111111111111"
// 6:		0xff 0x8d 0xff 0xff 0xff 0xff 0xff 0xff
#define SIX	"1111111110001101111111111111111111111111111111111111111111111111"
// 7: 		0xff 0x8e 0x7f 0xff 0xff 0xff 0xff 0xff
#define SEVEN	"1111111110001110111111111111111111111111111111111111111111111111"
// 8: 		0xff 0x91 0x7f 0xff 0xff 0xff 0xff 0xff
#define EIGHT	"1111111110010001011111111111111111111111111111111111111111111111"
// 9: 		0xff 0x93 0xff 0xff 0xff 0xff 0xff 0xff
#define NINE	"1111111110010011111111111111111111111111111111111111111111111111"
// stay:        0xff 0xd7 0xff 0xff 0xff 0xff 0xff 0xff
#define STAY	"1111111111010111111111111111111111111111111111111111111111111111"
// away:	0xff 0xd8 0xff 0xff 0xff 0xff 0xff 0xff
#define AWAY	"1111111111011000111111111111111111111111111111111111111111111111"

// predict thread
#define POPEN_FMT      "Rscript --vanilla /home/pi/all/R/predsvm2.R %s %s %s 2> /dev/null"
#define RARG_SIZE      256 // max number of characters allowed in argument to the Rscript
#define ROUT_MAX       256 // max number of characters read from output of Rscript
#define TS_BUF_SIZE    sizeof("2016-05-22T12:15:22Z")
#define PCMD_BUF_SIZE  (sizeof(POPEN_FMT) + TS_BUF_SIZE + 2 * RARG_SIZE) // size of buffer passed to popen()
#define INTZONES       {26, 27, 28, 29} // list of interior zones (zone numbering starts with 0)
#define EXITZONE       0 // zone number of front door which is main exit point from house
#define CONZONELL      0 // lower limit of concurent zone activity in seconds
#define CONZONEUL      10 // upper limit of concurent zone activity in seconds
#define PREDICT_UPDATE 5000000 // 5 ms predict thread update period in nanoseconds
#define PRLIGHTIP      "192.168.1.105" // IP addr of Playroom Light switch
#define MBLIGHTIP      "192.168.1.115" // Master Bedroom Light
#define BPLIGHTIP      "192.168.1.101" // Back Porch Light
#define FPLIGHTIP      "192.168.1.116" // Master Bedroom Light
#define SCMD_BUF_SIZE  sizeof("/home/pi/all/scripts/wemo.sh 192.168.1.105 OFF > /dev/null")
#define SCMD_FMT       "/home/pi/all/scripts/wemo.sh %s %s > /dev/null"
#define NUMPRED        10 // max number of predictions
#define MINPROB        50 // min probability estimate (in %) to be taken as valid

// message i/o thread
#define NUMZONES        32 // number of zones in system
#define MSG_IO_UPDATE   5000000 // 5 ms message io thread update period in nanoseconds

// structure to hold a snapshot of the panel status, sensor observations and predictions
struct status {
  char ledStatus[50];                       // panel main led status lights
  char zone1Status[50];                     // panel zone 1 status lights
  char zone2Status[50];                     // panel zone 2 status lights
  char zone3Status[50];                     // panel zone 3 status lights
  char zone4Status[50];                     // panel zone 4 status lights
  long unsigned obsTime;                    // zone sensor absolute observation time
  long unsigned zoneAct[32];                // zone sensor absolute activation times
  long unsigned zoneDeAct[32];              // zone sensor absolute deactivation times
  int numOcc;                               // estimated number of occupants in house
  char lastTruePred[NUMPRED][TS_BUF_SIZE];  // time of last true predictions
};

// global for direct gpio access
volatile unsigned *gpio;

// fifo globals
volatile int m_Read1, m_Write1, m_Read2, m_Write2;
volatile char m_Data1[FIFO_SIZE], m_Data2[FIFO_SIZE];

#ifdef TESTRT
// show_new_pagefault_count
static void show_new_pagefault_count(const char* logtext,
               const char* allowed_maj,
               const char* allowed_min) {
  static int last_majflt = 0, last_minflt = 0;
  struct rusage usage;

  getrusage(RUSAGE_SELF, &usage);

  fprintf(stdout, "%-30.30s: Pagefaults, Major:%ld (Allowed %s), " \
      "Minor:%ld (Allowed %s)\n", logtext,
      usage.ru_majflt - last_majflt, allowed_maj,
      usage.ru_minflt - last_minflt, allowed_min);

  last_majflt = usage.ru_majflt;
  last_minflt = usage.ru_minflt;
} // show_new_pagefault_count

/* prove_thread_stack_use_is_safe
 *
 * Note: gcc -Wall will complain here that buffer is set but not used.
 * This is because buffer is a local variable on the stack
 *   but not used outside the scope of this function.
 * This is why buffer is a volatile because otherwise complier would optimize it away.
 */
static void prove_thread_stack_use_is_safe(int stacksize) {
  volatile char buffer[stacksize];
  int i;

  // Prove that this thread is behaving well
  for (i = 0; i < stacksize; i += sysconf(_SC_PAGESIZE)) {
    // Each write to this buffer shall NOT generate a pagefault.
    buffer[i] = i;
  }

  show_new_pagefault_count("Caused by using thread stack", "0", "0");
} // prove_thread_stack_use_is_safe
#endif

// reserve_process_memory
static void reserve_process_memory(int size) {
  int i;
  char *buffer;

  buffer = malloc(size);

  // Touch each page in this piece of memory to get it mapped into RAM
  for (i = 0; i < size; i += sysconf(_SC_PAGESIZE)) {
    /* Each write to this buffer will generate a pagefault.
       Once the pagefault is handled a page will be locked in
       memory and never given back to the system. */
    buffer[i] = 0;
  }

  /* buffer will now be released. As Glibc is configured such that it
  never gives back memory to the kernel, the memory allocated above is
  locked for this process. All malloc() and new() calls come from
  the memory pool reserved and locked above. Issuing free() and
  delete() does NOT make this locking undone. So, with this locking
  mechanism we can build C/C++ applications that will almost never run into
  a major/minor pagefault, even with swapping enabled. */
  free(buffer);

  return;
} // reserve_process_memory

// Set up a memory regions to access GPIO
static void setup_io(void) {
  int  mem_fd;
  void *gpio_map;

  // open /dev/mem
  if ((mem_fd = open("/dev/mem", O_RDWR|O_SYNC) ) < 0) {
    perror("can't open /dev/mem \n");
    exit(EXIT_FAILURE);
  }

  // mmap GPIO
  gpio_map = mmap(
    NULL,             		//Any address in our space will do
    BLOCK_SIZE,						//Map length
    PROT_READ|PROT_WRITE,	//Enable reading & writing to mapped memory
    MAP_SHARED,						//Shared with other processes
    mem_fd,           		//File to map
    GPIO_BASE         		//Offset to GPIO peripheral
  );

  close(mem_fd); // No need to keep mem_fd open after mmap

  if (gpio_map == MAP_FAILED) {
    fprintf(stderr, "mmap error %d\n", (int) gpio_map); //errno also set!
    exit(EXIT_FAILURE);
  }

  // Always use volatile pointer!
  gpio = (volatile unsigned *)gpio_map;

  return;

} // setup_io

/* using clock_nanosleep of librt */
extern int clock_nanosleep(clockid_t __clock_id, int __flags,
                           __const struct timespec *__req,
                           struct timespec *__rem);

/*
 * the struct timespec consists of nanoseconds
 * and seconds. if the nanoseconds are getting
 * bigger than 1000000000 (= 1 second) the
 * variable containing seconds has to be
 * incremented and the nanoseconds decremented
 * by 1000000000.
 */
static inline void tnorm(struct timespec *tp)
{
   while (tp->tv_nsec >= NSEC_PER_SEC) {
      tp->tv_nsec -= NSEC_PER_SEC;
      tp->tv_sec++;
   }
}

/*
 * Calculate difference between two timespec variables.
 */
static inline long ts_diff(struct timespec *a, struct timespec *b)
{
  long x, y;

  x = (a->tv_sec)*NSEC_PER_SEC + a->tv_nsec;
  y = (b->tv_sec)*NSEC_PER_SEC + b->tv_nsec;

  return (x - y);
}

/*
 * Convert straight binary (represented by a char array) into an integer.
 * Variable offset defines where in the array to begin the conversion.
 * Variable length defines the size of the binary word to convert.
 */
static inline unsigned int getBinaryData(char *st, int offset, int length)
{
  unsigned int buf = 0, j;

  for (j = 0; j< length; j++) {
    buf <<=1;
    if ( *(st + offset + j) == '1' ) buf |= 1;
  }

  return buf;
}

/*
 * Fifos are thread safe without using any synchronization (e.g., mutext).
 * But each fifo must have exactly one producer and one consumer to be used safely.
 * See "Creating a Thread Safe Producer Consumer Queue in C++ Without Using Locks",
 * http://blogs.msmvps.com/vandooren
 */

// fifo1 - stores panel to keypad and keypad to panel data
static inline int pushElement1(char *element, int num) {
  int nextElement, i;

  // increment or reset pointer
  nextElement = ((m_Write1 + num) >= FIFO_SIZE) ? 0 : (m_Write1 + num);

  if (nextElement != m_Read1) { // fifo not full
    for (i = 0; i < num; i++) {
      m_Data1[m_Write1 + i] = element[i];
    }
  }

  // if fifo was full, data will be overwritten
  m_Write1 = nextElement;

  return i; // return number of elements pushed
}

static inline int popElement1(char *element, int num) {
  int nextElement, i;

  if (m_Read1 == m_Write1) {
    return 0; // fifo is empty
  }

  // increment or reset pointer
  nextElement = ((m_Read1 + num) >= FIFO_SIZE) ? 0 : (m_Read1 + num);

  for (i = 0; i < num; i++) {
    element[i] = m_Data1[m_Read1 + i];
  }

  m_Read1 = nextElement;

  return i;
}

// fifo2 - stores keypad data to be sent to panel
static inline int pushElement2(char *element, int num) {
  int nextElement, i;

  // increment or reset pointer
  nextElement = ((m_Write2 + num) >= FIFO_SIZE) ? 0 : (m_Write2 + num);

  if (nextElement != m_Read2) {
    for (i = 0; i < num; i++) {
      m_Data2[m_Write2 + i] = element[i];
    }
  } else {
    return 0; // fifo is full, data not overwritten
  }

  m_Write2 = nextElement;

  return i;
}

static inline int popElement2(char *element, int num) {
  int nextElement, i;

  if (m_Read2 == m_Write2) {
    return 0; // fifo is empty
  }

  // increment or reset pointer
  nextElement = ((m_Read2 + num) >= FIFO_SIZE) ? 0 : (m_Read2 + num);

  for (i = 0; i < num; i++) {
    element[i] = m_Data2[m_Read2 + i];
  }

  m_Read2 = nextElement;

  return i;
}
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
int main(int argc, char *argv[])
{
  int res, crit1, crit2, flag, i, port;
  struct sched_param param_main, param_pio, param_predict;
  struct utsname u;
  struct status pstat;
  pthread_t pio_thread, mio_thread, main_thread, predict_thread;
  pthread_attr_t my_attr;
  cpu_set_t cpuset_mio, cpuset_pio, cpuset_main;
  FILE *fd;

  // Check if user is running program as root. If not, exit.
  if(geteuid() != 0) {
    fprintf(stderr, "Program must be run as root\n");
    exit(EXIT_FAILURE);
  }

  // Check program args and get server port number.
  if (argc != 2) {
    fprintf(stderr, "usage: %s port<49152–65535>\n", argv[0]);
    exit(EXIT_FAILURE);
  } else {
    port = strtol(argv[1], NULL, 10);
    if (port < 49152 || port > 65535) {
      fprintf(stderr, "Port number must be in the range of 49152 to 65535\n");
      exit(EXIT_FAILURE);
    }
  }

  // Check if running with real-time linux.
  uname(&u);
  crit1 = (int) strcasestr (u.version, "PREEMPT RT");
  if ((fd = fopen("/sys/kernel/realtime","r")) != NULL) {
    crit2 = ((fscanf(fd, "%d", &flag) == 1) && (flag == 1));
    fclose(fd);
  }
  if (!(crit1 && crit2)) {
    fprintf(stderr, "Can't run under a vanilla kernel. Must be patched with PREEMPT RT.\n");
    exit(EXIT_FAILURE);
  }

  // CPU(s) for main, predict and message i/o threads
  CPU_ZERO(&cpuset_mio);
  CPU_SET(1, &cpuset_mio);
  CPU_SET(2, &cpuset_mio);
  CPU_SET(3, &cpuset_mio);
  CPU_ZERO(&cpuset_main);
  CPU_SET(1, &cpuset_main);
  CPU_SET(2, &cpuset_main);
  CPU_SET(3, &cpuset_main);
  // CPU(s) for panel i/o thread
  CPU_ZERO(&cpuset_pio);
  CPU_SET(0, &cpuset_pio);

  // Declare ourself as a real time task
  param_main.sched_priority = MAIN_PRI;
  if(sched_setscheduler(0, SCHED_FIFO, &param_main) == -1) {
    perror("sched_setscheduler failed\n");
    exit(EXIT_FAILURE);
  }

  // set main thread cpu affinity
  main_thread = pthread_self();
  res = pthread_setaffinity_np(main_thread, sizeof(cpuset_main), &cpuset_main);
  if (res) {
    perror("Main thread cpu affinity set failed\n");
    exit(EXIT_FAILURE);
  }

  // Lock memory to prevent page faults
  if(mlockall(MCL_CURRENT|MCL_FUTURE) == -1) {
    perror("mlockall failed\n");
    exit(EXIT_FAILURE);
  }

  // Turn off malloc trimming.
  mallopt(M_TRIM_THRESHOLD, -1);

  // Turn off mmap usage.
  mallopt(M_MMAP_MAX, 0);

  // Pre-fault our stack
  reserve_process_memory(MAX_SAFE_STACK);

  #ifdef TESTRT
  // display page fault status after pre-fault
  // number of pagefaults will not be zero
  show_new_pagefault_count("malloc() and touch generated", ">=0", ">=0");

  // Now allocate the memory for the 2nd time
  // number of pagefaults should be zero
  reserve_process_memory(MAX_SAFE_STACK);
  show_new_pagefault_count("2nd malloc() and use generated", "0", "0");

  // test that threads are safe
  prove_thread_stack_use_is_safe(100*1024);
  #endif

  // Set up gpio pointer for direct register access
  setup_io();

  // Set up FIFOs
  m_Read1 = 0;
  m_Read2 = 0;
  m_Write1 = 0;
  m_Write2 = 0;
  for (i = 0; i < MAX_DATA; i++) {
    m_Data1[i] = '0';
    m_Data2[i] = '0';
  }

  // init panel status indicators
  memset(&pstat, 0, sizeof(pstat));

  // Set pin direction
  INP_GPIO(PI_DATA_OUT); // must use INP_GPIO before we can use OUT_GPIO
  OUT_GPIO(PI_DATA_OUT);
  INP_GPIO(PI_DATA_IN);
  INP_GPIO(PI_CLOCK_IN);

  // Set PI_DATA_OUT pin low.
  GPIO_CLR = 1<<PI_DATA_OUT;

  // create panel input / output thread
  pthread_attr_init(&my_attr);
  pthread_attr_setinheritsched (&my_attr, PTHREAD_EXPLICIT_SCHED);
  pthread_attr_setaffinity_np(&my_attr, sizeof(cpuset_pio), &cpuset_pio);
  pthread_attr_setschedpolicy(&my_attr, SCHED_FIFO);
  // Set the requested stacksize for this thread
  res = pthread_attr_setstacksize(&my_attr, PTHREAD_STACK_MIN + MY_STACK_SIZE);
  if (res) {
    perror("Panel i/o thread set stack size failed\n");
    exit(EXIT_FAILURE);
  }
  param_pio.sched_priority = PANEL_IO_PRI;
  pthread_attr_setschedparam(&my_attr, &param_pio);
  res = pthread_create(&pio_thread, &my_attr, panel_io, NULL);
  if (res) {
    perror("Panel i/o thread creation failed\n");
    exit(EXIT_FAILURE);
  }
  pthread_attr_destroy(&my_attr);

  // create message input / output thread
  pthread_attr_init(&my_attr);
  pthread_attr_setinheritsched (&my_attr, PTHREAD_EXPLICIT_SCHED);
  pthread_attr_setaffinity_np(&my_attr, sizeof(cpuset_mio), &cpuset_mio);
  pthread_attr_setschedpolicy(&my_attr, SCHED_FIFO);
  // Set the requested stacksize for this thread
  res = pthread_attr_setstacksize(&my_attr, PTHREAD_STACK_MIN + MY_STACK_SIZE);
  if (res) {
    perror("Message i/o thread set stack size failed\n");
    exit(EXIT_FAILURE);
  }
  param_pio.sched_priority = MSG_IO_PRI;
  pthread_attr_setschedparam(&my_attr, &param_pio);
  res = pthread_create(&mio_thread, &my_attr, msg_io, (void *) &pstat);
  if (res) {
    perror("Message i/o thread creation failed\n");
    exit(EXIT_FAILURE);
  }
  pthread_attr_destroy(&my_attr);

  // create predict thread
  pthread_attr_init(&my_attr);
  pthread_attr_setinheritsched (&my_attr, PTHREAD_EXPLICIT_SCHED);
  pthread_attr_setaffinity_np(&my_attr, sizeof(cpuset_mio), &cpuset_mio);
  pthread_attr_setschedpolicy(&my_attr, SCHED_FIFO);
  // Set the requested stacksize for this thread
  res = pthread_attr_setstacksize(&my_attr, PTHREAD_STACK_MIN + MY_STACK_SIZE);
  if (res) {
    perror("Predict thread set stack size failed\n");
    exit(EXIT_FAILURE);
  }
  param_predict.sched_priority = PREDICT_PRI;
  pthread_attr_setschedparam(&my_attr, &param_predict);
  res = pthread_create(&predict_thread, &my_attr, predict, (void *) &pstat);
  if (res) {
    perror("Predict thread creation failed\n");
    exit(EXIT_FAILURE);
  }
  pthread_attr_destroy(&my_attr);

  // start server
  panserv(&pstat, port);

  // cleanup - unlock memory
  if(munlockall() == -1) {
    perror("munlockall failed\n");
    exit(EXIT_FAILURE);
  }

  return(0);
} // main

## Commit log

2015-12-10 added netbus schematic to readme
2015-12-24 updated interface schematic in README.md
2015-12-24 init commit v1.1
    [interface-v1.1.sch]
2016-01-09 updated readme; BOM costs and typos
2016-02-26 mods to panserv to reflect more logical flow
2016-02-28 fixed zone numbering, now all labled 1 to 8
    [kprw-server.c]
2016-05-16 init commit
    [knnTrain.csv, testFromSimpledb.csv]
2016-05-17 modified predict thread to output entire R prediction
2016-05-23 latest observation database
    [testFromSimpledb.csv]
2016-05-28 latest database
    [testFromSimpledb.csv]
2016-06-05 updated panel_io thread fault handling
2016-06-14 replaced modulus operator in fifos w/simpler code
    [kprw-server.c]
2016-07-04 fixed sendJSON cmd string compare length
    [kprw-server.c]
2016-07-11 added last prediction status and cleaned up prediction thread
2016-07-30 changed rules in predict thread; removed misc debug; misc cleanup
2016-07-30 findPlacesNotReady now ignores motion sensors
2016-08-08 current observation dataset
    [panelSimpledb.csv]
2016-09-04 latest sensor database
    [panelSimpledb.csv]
2016-09-04 test database - no longer used
    [testFromSimpledb.csv]
2016-10-16 fixed typo in comment
    [kprw-server.c]
2016-12-18 findPlacesNotReady modified and used in place of zonesNotActive to fix motion sensors stopping arming
2017-04-01 force lower case on ASR return values, part of #34
2019-07-20 updated schematic and added pcb layout
    [interface-v1.1.sch, kicad.kicad_pcb, kicad.sch]
2019-08-04 fixed pcb footprint for OSTTC020162
    [kicad.kicad_pcb, kicad.sch]
2019-08-05 added pcb photos
2019-09-09 replace strncpy w/memcpy to avoid nul termination
    [kprw-server.c]
2019-09-09 use short int for zone index to prevent overflow warn
    [kprw-server.c]
2019-09-09 increase str size to prevent possible overflow
    [kprw-server.c]
2019-09-09 changes to prevent possible truncation in popen() to R
    [kprw-server.c]
2019-09-11 fix bad panel reads after upgrade to 4.19.59-rt23-v7+
    [kprw-server.c]
2019-09-14 log short panel word reads to stdout instead of stderr
    [kprw-server.c]
2019-09-15 add real time test data
    [pi-rt-histogram.ods, pi2-rt-histogram.csv, pi3-rt-histogram.csv]

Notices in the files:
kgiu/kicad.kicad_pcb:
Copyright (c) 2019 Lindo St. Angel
